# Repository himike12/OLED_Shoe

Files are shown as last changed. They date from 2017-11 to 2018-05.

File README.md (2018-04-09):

# OLED_Shoe

This is the git repository for both the mobile application as well as the hardware design and code.

The Hardware file includes all of the files relating to the hardware design as well as the software for the embedded microcontroller.

Dependencies:

Linux
For 64-bit Linux users, libc6:i386, libstdc++6:i386, libncurses5:i386 and libudev1:i386 need to be installed :
  * sudo dpkg --add-architecture i386
  * sudo apt-get update
  * sudo apt-get -y install libc6:i386 libstdc++6:i386 libncurses5:i386 libudev1:i386
  
From the Library Manager:
  * Adafruit_GFX_Library
  * BLEPeripheral
  * PL_microEPD

Programmer:
  * CMSIS-DAP

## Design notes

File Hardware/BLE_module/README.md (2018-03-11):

The BLE_Serial_Echo and BLE_Serial_No_Echo use the Arduino IDE.

In order to use the Arduino IDE with the Nordic nRF52, you need to install aditional stuff in the Arduino IDE. The link below has instructions on how to install everything needed.

https://github.com/sandeepmistry/arduino-nRF5

File Contents

BLE_Serial_Programs - Contains test programs related to bluetooth low energy (BLE)

Combine_Screen_and_BLE - Contains test programs that combine the use of BLE and the ePaper screens

Screen_Test_Code - Contains test code related to displaying content on the ePaper screens

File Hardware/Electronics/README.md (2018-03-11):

File Contents

Adafruit_Designs - Contains the original schematic diagrams and PCB designs for parts that were used in the project. Some of the schematic diagrams have been coped and modified to work in the project.

ePaperShoe - Contains the schematic diagrams and PCB designs created for the project

nRF52_Reference_Scematics - Contains the reference documents for the Nordic nRF52-DK

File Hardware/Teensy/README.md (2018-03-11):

File Contents

Teensy_Game_OF_Life - A program for the Teensy that will display the game of life on the ePaper screen

Teensy_Screen_Demo - A program for the Teensy that will display a test image on the ePaper screen

Working_PL_Teensy_GFXDemo - A program for the Teensy that will display a GFX demo on the ePaper screen

Working_PL_Teensy_HelloWorld - A program for the Teensy that will display text saying "Hello World" on the ePaper screen

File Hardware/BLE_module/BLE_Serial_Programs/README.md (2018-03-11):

File contents

BLE_Serial_Echo - A program for the Nordic nRF52 that will communicate with a mobile device running an application that will connect to the microcontroller using BLE UART, such as Bluefruit from Adafruit. The text entered on the mobile device will be echoed back the to the mobile device and sent to a serial connection  and vice versus.

BLE_Serial_Echo - A program for the Nordic nRF52 that will communicate with a mobile device running an application that will connect to the microcontroller using BLE UART, such as Bluefruit from Adafruit. The text entered on the mobile device will be sent to a serial connection and vice versus.

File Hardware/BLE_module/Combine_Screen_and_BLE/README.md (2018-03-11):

File Contents

recieve_data_and_display_modes - A program for the Nordic nRF52 that will display different images on the ePaper screen and run in different modes depending on the instructions that it receives over BLE UART.

recieve_data_and_display_the_text - A program for the Nordic nRF52 that will display text that it has received over BLE UART.

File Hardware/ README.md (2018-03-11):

File contents

BLE_module - Contains all of the code written for the Nordic nRF52832 microcontroller

Electronics - Contains all of the schematic diagrams and PCB designs created as well as reference designs from Adafruit and Nordic

Example Code - Contains reference documents from PlasticLogic, Paperino, and Img2Code

Teensy - Contains all of the code written for the Teensy microcontroller

TestImages - Contains all the images that have been converted to be displayed on the ePaper screens

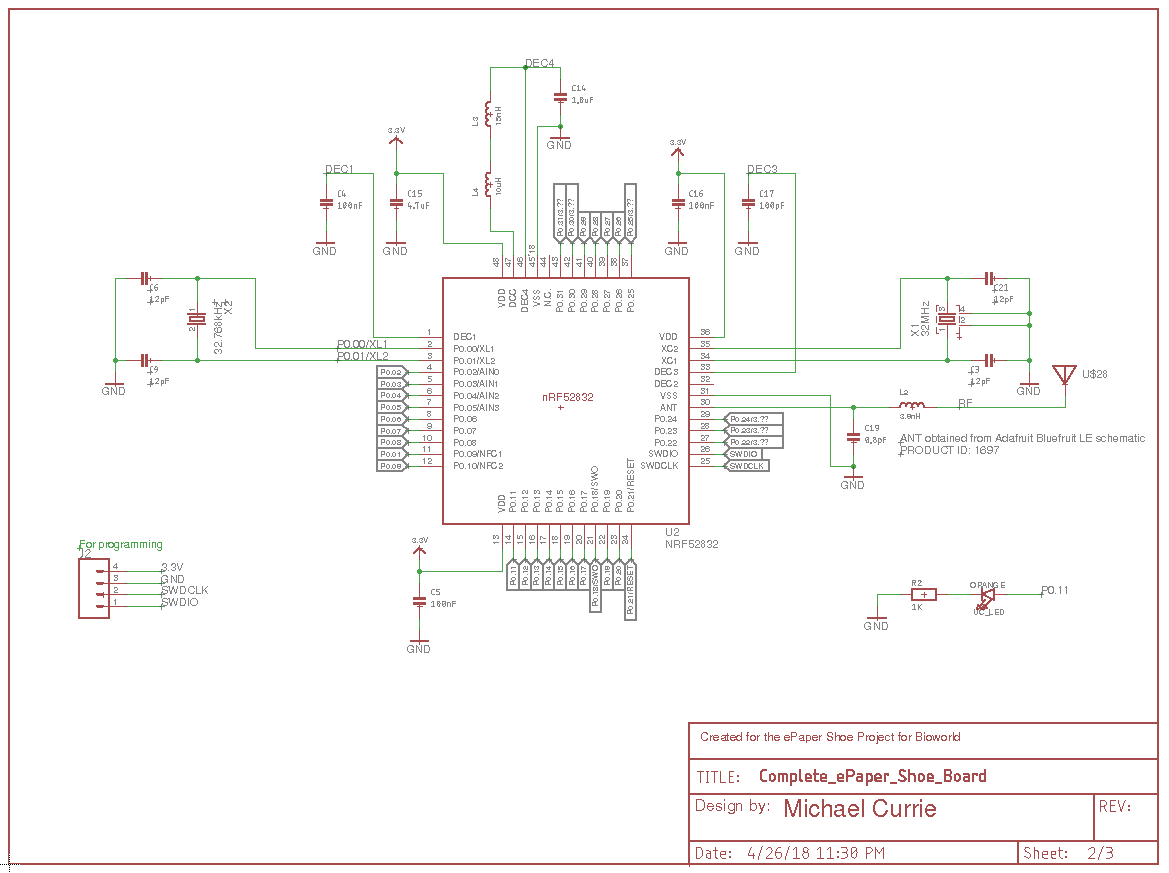
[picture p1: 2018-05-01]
Hardware/Images/Schematic2.png

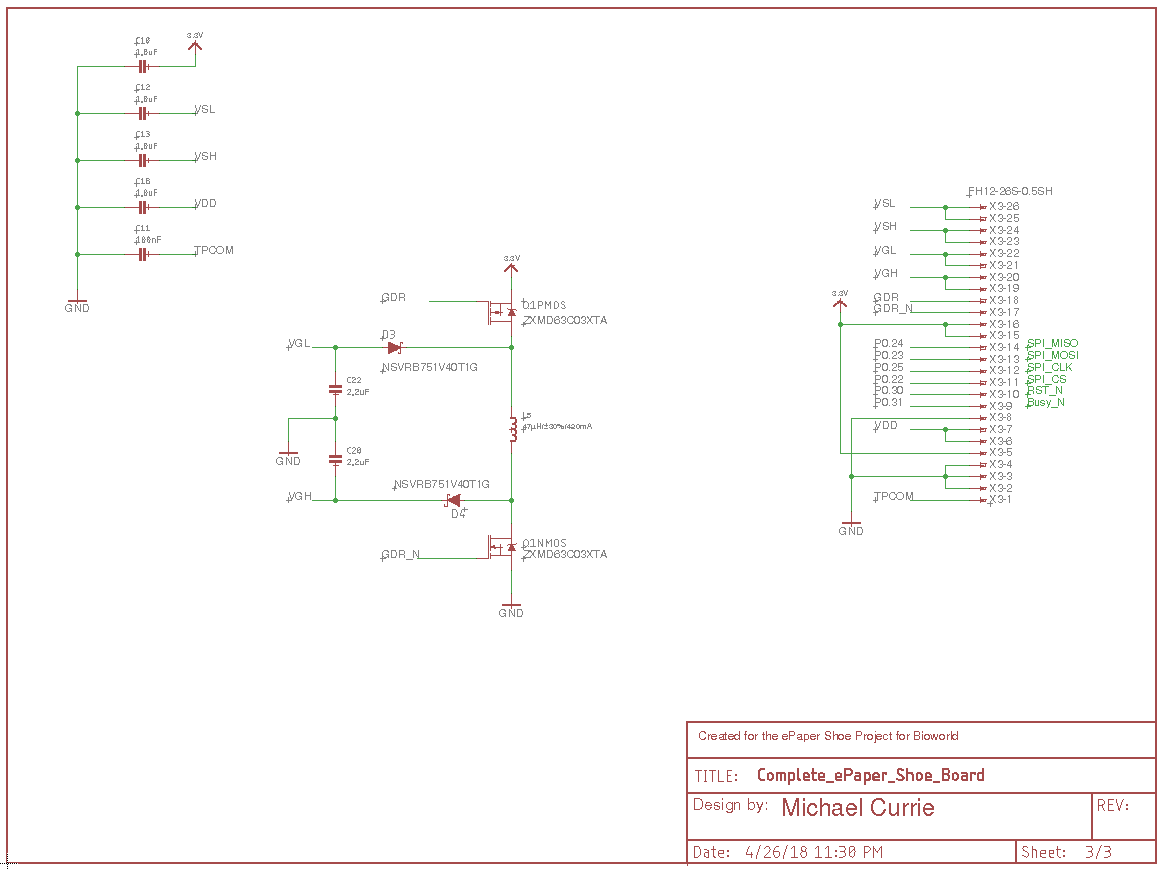
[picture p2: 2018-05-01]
Hardware/Images/Schematic3.png

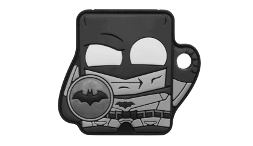
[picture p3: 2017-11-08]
Hardware/ExampleCode/PlasticLogic_SD_Card_Contents/S021_T1.1/img/batman9.PNG

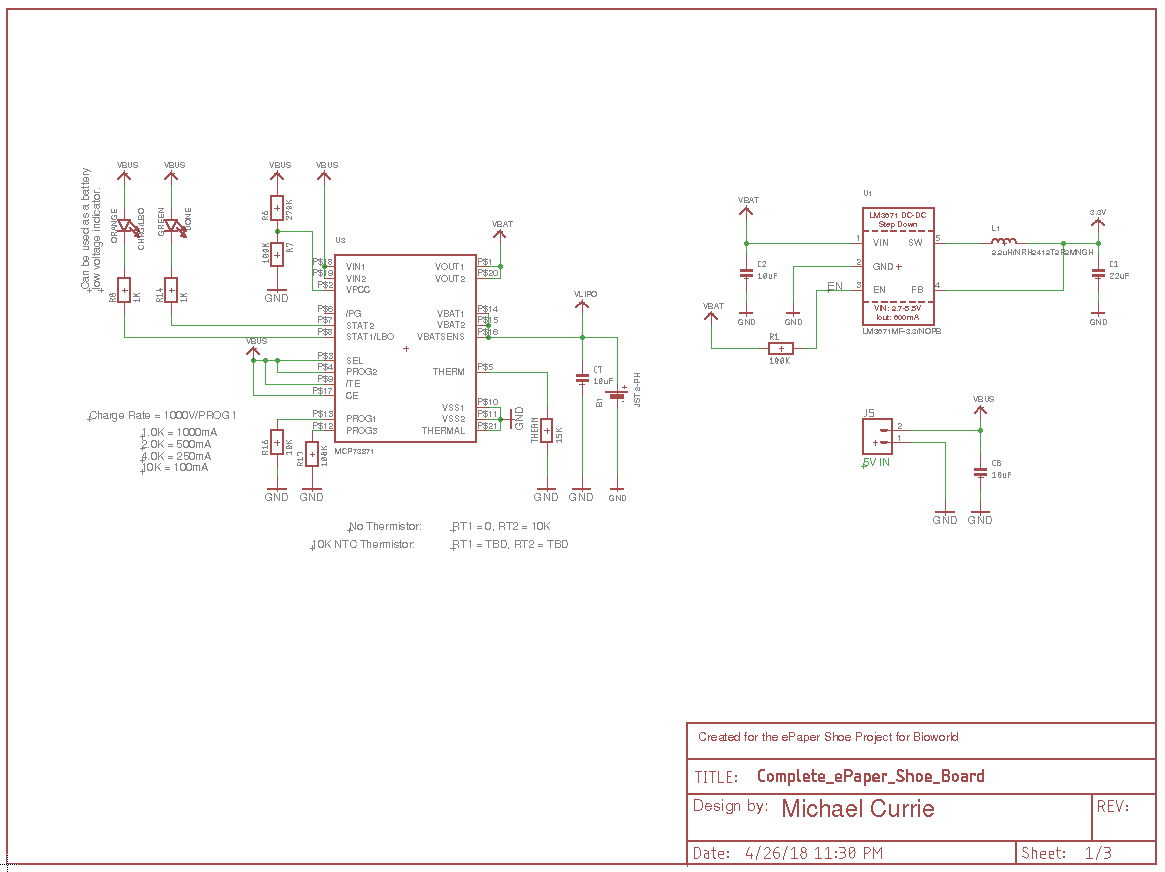
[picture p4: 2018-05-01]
Hardware/Images/Schematic1.png

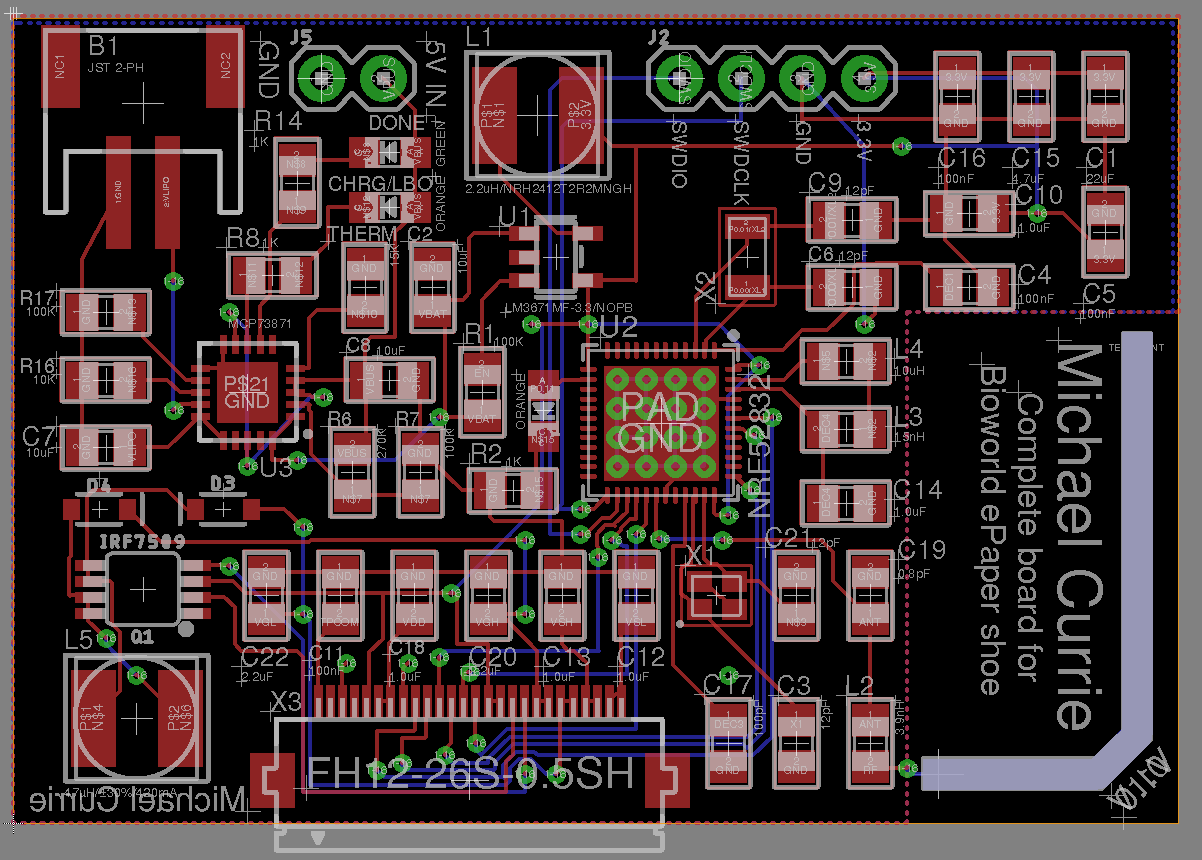
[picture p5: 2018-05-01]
Hardware/Images/PCB.png

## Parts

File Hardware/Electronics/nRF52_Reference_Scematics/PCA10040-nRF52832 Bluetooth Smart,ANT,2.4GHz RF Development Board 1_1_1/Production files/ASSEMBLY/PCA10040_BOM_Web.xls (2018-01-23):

Bill of material
PCB: | PCA10040
Version: | 1.1.1
Designator | Value | Description | Footprint Doc | Manufacturer | Manufacturer Part Number
Bat1 | Bat Holder CR2032 | Bat Holder CR2032 SMD | CR2032_HOLDER_SMD | Comfortable | BC-2001
C1, C2, C11, C12 | 12pF | Capacitor, NP0, ±2% | 0402
C3 | 0.8pF | Capacitor, NP0, ±5% | 0402
C4, C5, C8, C18, C19, C21, C24, C25, C26, C27, C28, C29, C32, C34, C35, C36, C38, C39, C40, C41, C44, C45, C46, C47 | 100nF | Capacitor, X7R, ±10% | 0402
C6, C13 | N.C. | Not mounted | 0402
C7 | 100pF | Capacitor, NP0, ±5% | 0402
C9 | 4.7µF | Capacitor, X5R, ±10% | 0603
C10, C16, C17 | 1.0µF | Capacitor, X7R, ±10% | 0603
C15 | 1.2pF | Capacitor, NP0, ±0.1pF | 0402
C20, C31, C33 | 10µF | Capacitor, X5R, ±20% | 0603
C22, C23 | 18pF | Capacitor, NP0, ±5% | 0402
C30 | 10nF | Capacitor, X7R, ±10% | 0402
C37 | 10pF | Capacitor, NP0, ±2% | 0402
C42, C43 | 300pF | Capacitor, NP0, ±5% | 0402
C48, C49, C50, C51 | 1.0µF | Capacitor, X5R, ±5% | 0402
D1 | SD103ATW-7-F | Surface Mount Schottky Barrier Diode Array | SOT-363 | Diodes Incorporated | SD103ATW-7-F
D2 | PRTR5V0U2X | Ultra low capacitance double rail-to-rail ESD protection diode | SOT-143B | NXP | PRTR5V0U2X
D3, D4, D5, D6 | 1PS79SB30.115 | Diode Schottky Vf=0.38, Vr=40V, If=200mA, Ir=500nA | SOD-523 | NXP | 1PS79SB30.115
J1 | MM8130-2600 | Coaxial Connector with Switch | COAXIAL-SWF | Murata | MM8130-2600
J2 | MicroUSB-B | MicroUSB-B-SMT | USB-Micro-B-RA-SMD-PiP | Allen Creations Corp. | AJU55-BS2111-L
L1 | 3.9nH | Inductor, 170mA, ±0.1nH | 0402 | Murata | LQP15MN3N9B02D
L2 | 10µH | Inductor, 80mA, ±10% | 0603 | Taiyo Yuden | LBMF1608T100K
L3 | 15nH | Inductor, 320mA, ±5% | 0402 | Taiyo Yuden | HK100515NJ-T
LD5 | LTST-C195KGJRKT | Ultra bright AlInGaP Bi-Color LED | LED_DUAL_0606 | Lite-On Inc | LTST-C195KGJRKT
LED1, LED2, LED3, LED4 | L0603G | LED SmartLED Green 570nm 0603 | 0603 | OSRAM Opto Semi | LG L29K-G2J1-24-Z
P1, P3 | Socket 1x8 | Socket 1x8, 2.54mm (100mil), SMD | SOCKET_1x8_SMD | WCON | 2171-108MS0CUNR1
P2 | Socket 1x6 | Socket 1x6, 2.54mm (100mil), SMD | SOCKET_1x6_SMD | WCON | 2171-106MS0CUNR1
P4 | Socket 1x10 | Socket 1x10, 2.54mm (100mil), SMD | SOCKET_1x10_SMD | WCON | 2171-110MS0CUNR1
P5 | Pin Hdr 2x3 | Pin Header 2x3, 2.54mm (100mil) SMD | HDR_2x3-SMD | WCON | 1125-1203S0M116R1
P6 | Socket 1x9 | Socket 1x9, 2.54mm (100mil), SMD | SOCKET_1x9_SMD | WCON | 2171-109MS0CUNR1
P7, P9 | Pin List 1x8 | Pin List 1x8, 2.54mm (100mil), SMD | LIST_1x8_SMD
P8 | Pin List 1x6 | Pin List 1x6, 2.54mm (100mil), SMD | LIST_1x6_SMD
P10 | Pin List 1x10 | Pin List 1x10, 2.54mm (100mil), SMD | LIST_1x10_SMD
P11 | Socket 2x3 | Socket 2x3, 2.54mm (100mil), SMD | SOCKET_2x3_SMD-2.54mm-bottom
P12 | Pin List 1x9 | Pin List 1x9, 2.54mm (100mil), SMD | LIST_1x9_SMD
P13, P15 | Pin Header 2x8 | Pin Header 2x8, 2.54mm (100mil) | HDR_2x8
P14 | Pin Header 2x6 | Pin Header 2x6, 2.54mm (100mil) | HDR_2x6
P16 | Pin Header 2x10 | Pin Header 2x10, 2.54mm (100mil) | HDR_2x10
P17 | Pin Header 2x9 | Pin Header 2x9, 2.54mm (100mil) | HDR_2x9
P18, P19 | Pin Header 2x5, 1.27mm | Pin Header 2x5, 1.27mm (50mil), SMD, Keying Shroud | HDR_2x5-SMD-1.27mm | WCON | 3132-10MS0BK00R1
P20 | Pin List 1x8 | Pin List 1x8, 2.54mm (100mil), SMD | LIST_1x8_SMD | WCON | 1125-1108S0M116R2
P21, P22 | Pin List 1x2, Angled | Pin List 1x2, 2.54mm (100mil), Right Angled, SMD | LIST_ANG_1x2-SMD-2.54MM | WCON | 1125B-1102S0Z135R2
P23 | FPC 0.5mm RA SMD | 0.5mm FPC, 5P,Right Angle SMT,Double Contact,H=1.2mm,White, Goldflash | FPC_05P-0.5mm-RA-SMD | WCON | 5141-05RZDNWR02
Q1, Q2 | FDG6321C | Fairchild, FDG6321C, Dual N & P Channel Digital FET | SC70-6 | Fairchild | FDG6321C
R1, R2, R3, R4, R19, R20 | 220R | Resistor, ±1%, 0.063W | 0402
R5, R8, R9, R10, R11, R12 | 10k | Resistor, ±1%, 0.063W | 0402
R6, R27, R28, R37 | N.C. | Not mounted | 0402
R7 | 47k | Resistor, ±1%, 0.063W | 0402
R13, R14 | 39R | Resistor, ±1%, 0.063W | 0402
R15, R16 | 150R | Resistor, ±1%, 0.063W | 0402
R17 | 6k8 | Resistor, ±1%, 0.063W | 0402
R18 | 1k | Resistor, ±1%, 0.063W | 0402
R21, R22, R23, R24, R29, R30 | 4k7 | Resistor, ±1%, 0.063W | 0402
R25, R26, R38 | 0R | Resistor, ±5%, 0.063W | 0402
R31, R32 | 12k | Resistor, ±1%, 0.063W | 0402
R33, R34, R35, R36 | 100k | Resistor, ±1%, 0.063W | 0402
R39 | 1M0 | Resistor, ±1%, 0.063W | 0402
R40, R41, R42, R43 | 18k | Resistor, ±1%, 0.063W | 0402
SW1, SW2, SW3, SW4, SW5 | PB SW | Tactile Switch, SPNO, SMD, 6.5x6.2x2.5mm | ALPS_SKHUxxx010_WO_GND | Dalywell | TS604VM1-025BR-R
SW6 | Switch | SMD slide Switch (ON-ON) | JS202011SCQN | Dalywell | SS206VM-G2-LLR-R
U1 | nRF52832-QFAA | Multi-protocol Bluetooth Low Energy and 2.4GHz proprietary system-on-chip | QFN-48 | Nordic Semiconductor | nRF52832-QFAA
U2 | ATSAM3U2CA-AU | IC MCU 32bit 128kB flash 100LQFP | LQFP-100 | Atmel | ATSAM3U2CA-AU
U3 | AP7333-33SAG-7 | 300mA, Low Quiescent Current, Fast Transient Low Dropout Linear Regulator | SOT-23-3 | Diodes Incorporated | AP7333-33SAG-7
U4, U5, U6 | NX3DV2567 | Low-ohmic four-pole double-throw analog switch | XQFN-16 | NXP Semiconductors | NX3DV2567GU
U7 | PCAL6408A | 8-bit I2C-bus I/O expander with interrupt output | XQFN-16 | NXP Semiconductors | PCAL6408AHK
X1 | 32MHz | XTAL SMD 2016, 32MHz, Cl=8pF, Tol: ±10ppm, Stab: ±10ppm | XTAL_2016 | Epson Toyocom | Q22FA12800025
X2 | 32.768kHz | EPSON TOYOCOM - FC-135 32.768KHZ ±20PPM,9.0PF - CRYSTAL, SM, WATCH | XTAL_3215 | Epson Toyocom | FC-135 32.768KHZ ±20PPM,9.0PF
X3 | 12MHz | XTAL SMD 3225, 12MHz, 18pF, ±30ppm | BT-XTAL_3225 | TXC Corporation | 7M-12.000MAAJ-T

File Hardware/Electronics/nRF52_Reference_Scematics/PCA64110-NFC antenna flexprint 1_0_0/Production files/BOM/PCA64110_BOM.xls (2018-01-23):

Bill of material
PCB: | PCA64110
Version: | 1.0.0
Supplier | Supplier Part Number | Contact information
Elprint Norge | 203406 | Web: www.elprint.no Phone: +47 55 92 55 00

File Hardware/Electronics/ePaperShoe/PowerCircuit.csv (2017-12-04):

Added | Qty | Value | Device | Package | Parts | Description | DESIGNER | PROD_ID | VERSION
y | 1 |  | CONN_04 | 1X04 | J1 | Multi connection point. Often used as Generic Header-pin footprint for 0.1 inch spaced/style header connections |  | CONN-09696
y | 3 | 100K | RESISTOR0805_NOOUTLINE | 0805-NO | R1, R7, R17 | Resistors
y | 1 | 10K | RESISTOR0805_NOOUTLINE | 0805-NO | R16 | Resistors
y | 3 | 10uF | CAP_CERAMIC0805-NOOUTLINE | 0805-NO | C2, C7, C8 | Ceramic Capacitors
y | 1 | 15K | RESISTOR0805_NOOUTLINE | 0805-NO | THERM | Resistors
y | 2 | 1K | RESISTOR0805_NOOUTLINE | 0805-NO | R8, R14 | Resistors
y | 1 | 2.2uH/NRH2412T2R2MNGH | INDUCTORNRH2412T | INDUCTOR_TAIYOYUDEN_NRH2412T | L1 | Inductors
y | 1 | 22uF | CAP_CERAMIC0805-NOOUTLINE | 0805-NO | C1 | Ceramic Capacitors
y | 1 | 270K | RESISTOR0805_NOOUTLINE | 0805-NO | R6 | Resistors
n/a | 1 | FRAME-LETTER-MICHAELNO_PACKAGE | FRAME-LETTER-MICHAELNO_PACKAGE | DUMMY | FRAME1 | Schematic Frame - Letter | Nobody |  | v01
y | 1 | GREEN | LED0805_NOOUTLINE | CHIPLED_0805_NOOUTLINE | DONE | LED
y | 1 | JST 2-PH | BATTERY | JSTPH2 | B1 | CR1220 SMT - Digikey: 3001K-ND
y | 1 | LM3671MF-3.3/NOPB | VREG_LM3671 | SOT23-5 | U1 | LM3671 - 600mA DC-DC Step-Down Converter
y | 1 | MCP73871 | MCP73871 | QFN20_4MM | U3 | MCP73871 Lithium Polymer Battery Charger
y | 1 | MicroUSB | USBMICRO_20329 | 4UCONN_20329 | CN4 | USB Connectors
y | 1 | ORANGE | LED0805_NOOUTLINE | CHIPLED_0805_NOOUTLINE | CHRG/LBO | LED

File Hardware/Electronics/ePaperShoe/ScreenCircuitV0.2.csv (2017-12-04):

Added top order | Part | Value | Device | Package | Description | DESIGNER | MF | MPN | OC_FARNELL | OC_NEWARK | PACKAGE | PROD_ID | SUPPLIER | VALUE | VERSION
y | C1 | 1.0uF | 1.0UF-1206-50V-10% | 1206 | 1µF ceramic capacitors |  |  |  |  |  |  | CAP-09822 |  | 1.0uF
y | C2 | 1.0uF | 1.0UF-1206-50V-10% | 1206 | 1µF ceramic capacitors |  |  |  |  |  |  | CAP-09822 |  | 1.0uF
y | C3 | 1.0uF | 1.0UF-1206-50V-10% | 1206 | 1µF ceramic capacitors |  |  |  |  |  |  | CAP-09822 |  | 1.0uF
y | C4 | 1.0uF | 1.0UF-1206-50V-10% | 1206 | 1µF ceramic capacitors |  |  |  |  |  |  | CAP-09822 |  | 1.0uF
y | C5 | 0.1uF | 0.1UF-0603-100V-10% | 603 | 0.1µF ceramic capacitors |  |  |  |  |  |  | CAP-08390 |  | 0.1uF
y | C6 | 4.7uF | 4.7UF-1206-16V-(+80/-20%) | 1206 | 4.7µF ceramic capacitors |  |  |  |  |  |  | CAP-10300 |  | 4.7uF
y | C7 | 4.7uF | 4.7UF-1206-16V-(+80/-20%) | 1206 | 4.7µF ceramic capacitors |  |  |  |  |  |  | CAP-10300 |  | 4.7uF
y | D3 | 0.5A/40V/420mV | DIODE-SCHOTTKY-PMEG4005EJ | SOD-323 | Schottky diode |  |  |  |  |  |  | DIO-10955 |  | 0.5A/40V/420mV
y | D4 | 0.5A/40V/420mV | DIODE-SCHOTTKY-PMEG4005EJ | SOD-323 | Schottky diode |  |  |  |  |  |  | DIO-10955 |  | 0.5A/40V/420mV
n/a | FRAME1 | FRAME-LETTER-MICHAELNO_PACKAGE | FRAME-LETTER-MICHAELNO_PACKAGE | DUMMY | Schematic Frame - Letter | Nobody |  |  |  |  |  |  |  |  | v01
y | J1 |  | CONN_08";"1X08 | Multi connection point. Often used as Generic Header-pin footprint for 0.1 inch spaced/style header connections |  |  |  |  |  |  | CONN-08438
y | L1 | 47µH/±30%/750mA | INDUCTOR-CR54-47UH | CR54 | Inductors |  |  |  |  |  |  | NDUC-10789 |  | 47µH/±30%/750mA
y | Q1 | IRF7509 | IRF7509 | MSOP8 | Dual N and P Channel MOSFET |  |  |  |  |  |  | TRANS-07913
y | U1 | XF2J-2624-11A | XF2J-2624-11A | OMRON_XF2J-2624-11A | FFC/FPC CONNECTOR, RECEPTACLE 26POS 1ROW |  |  | XF2J-2624-11A | - | 05M1981 | FFC/FPC CONNECTOR, RECEPTACLE 26POS 1ROW |  | OMRON ELECTRONIC COMPONENTS
y | X1 | FH12-26S-0.5SH | FH12-26S-0.5SH | FH12-26S-0.5SH | 0.5mm Pitch Connectors For FPC/FFC |  |  | FH12-26S-0.5SH(55) | 1324553 | 34M6172

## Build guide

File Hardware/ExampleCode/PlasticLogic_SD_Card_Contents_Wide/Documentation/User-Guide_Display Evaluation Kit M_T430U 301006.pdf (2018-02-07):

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
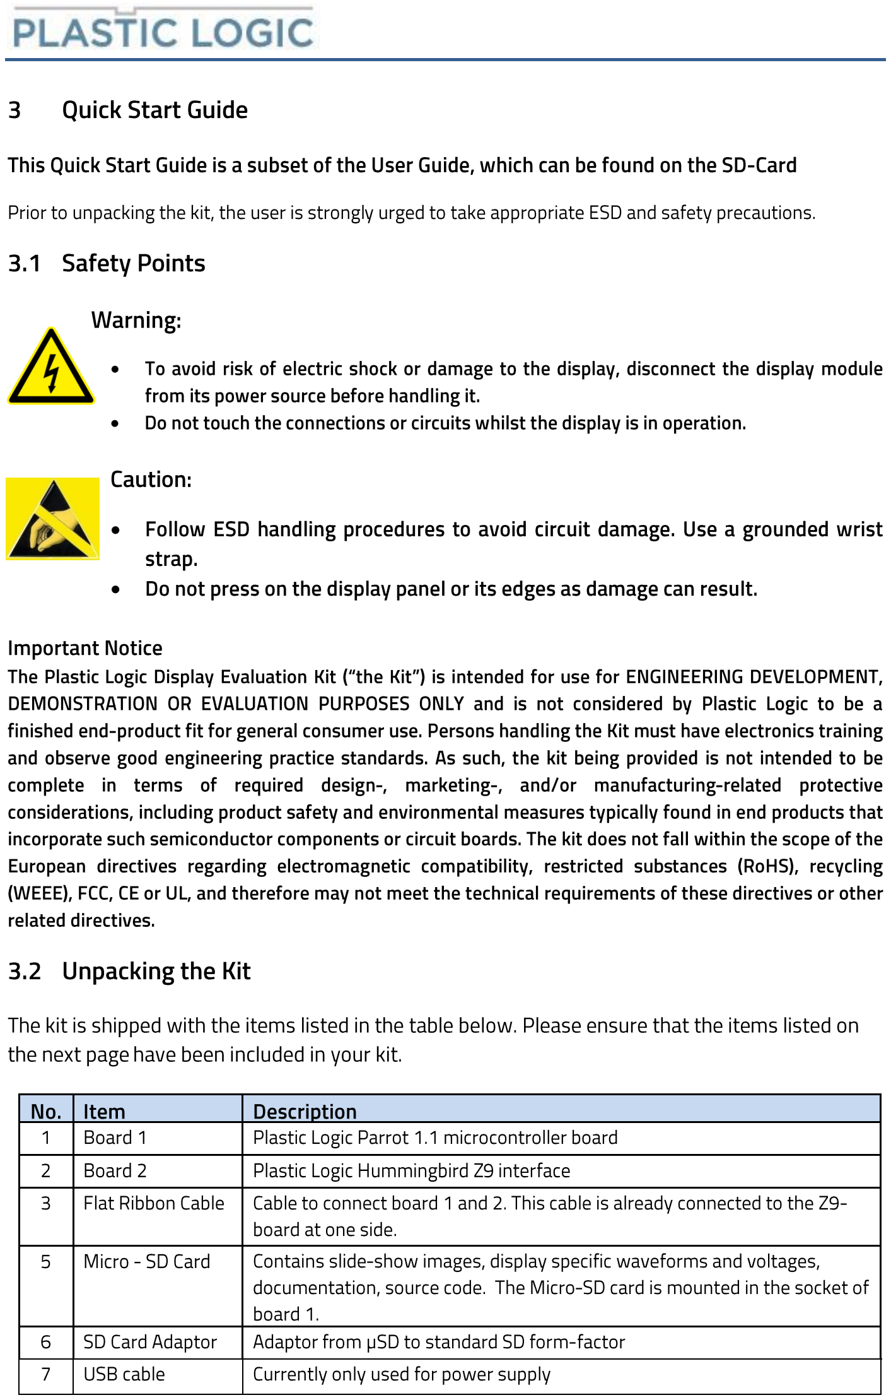
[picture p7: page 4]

••••

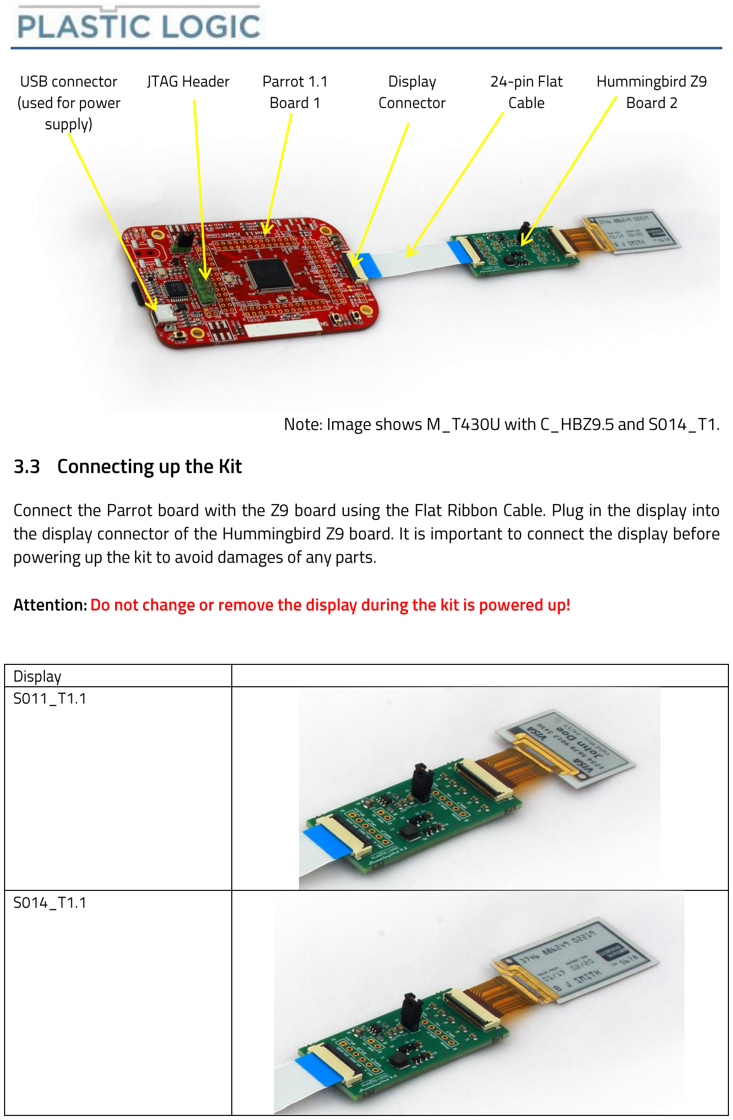
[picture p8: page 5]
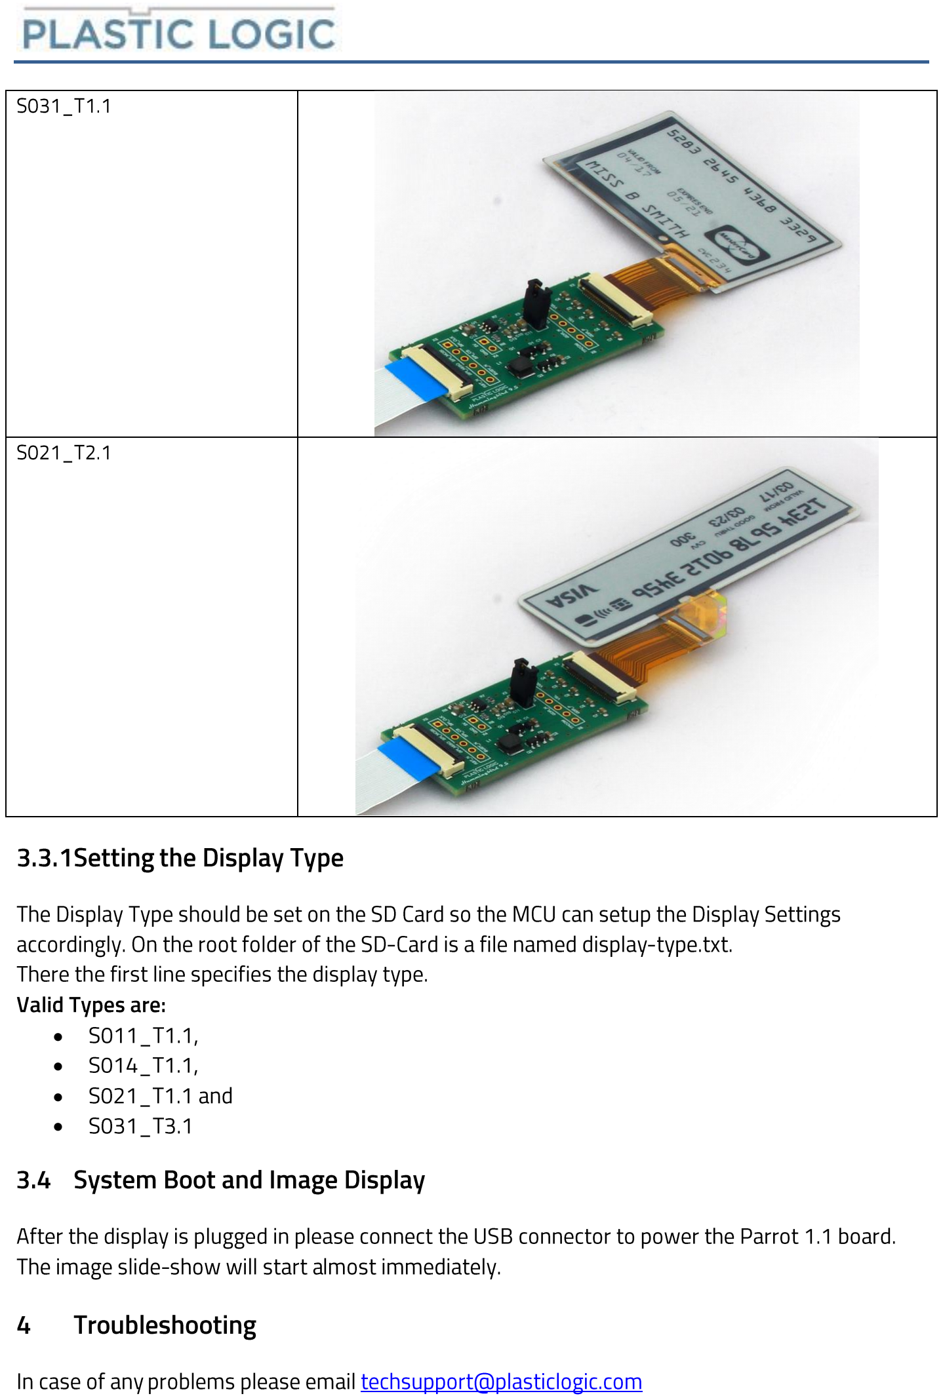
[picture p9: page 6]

••••

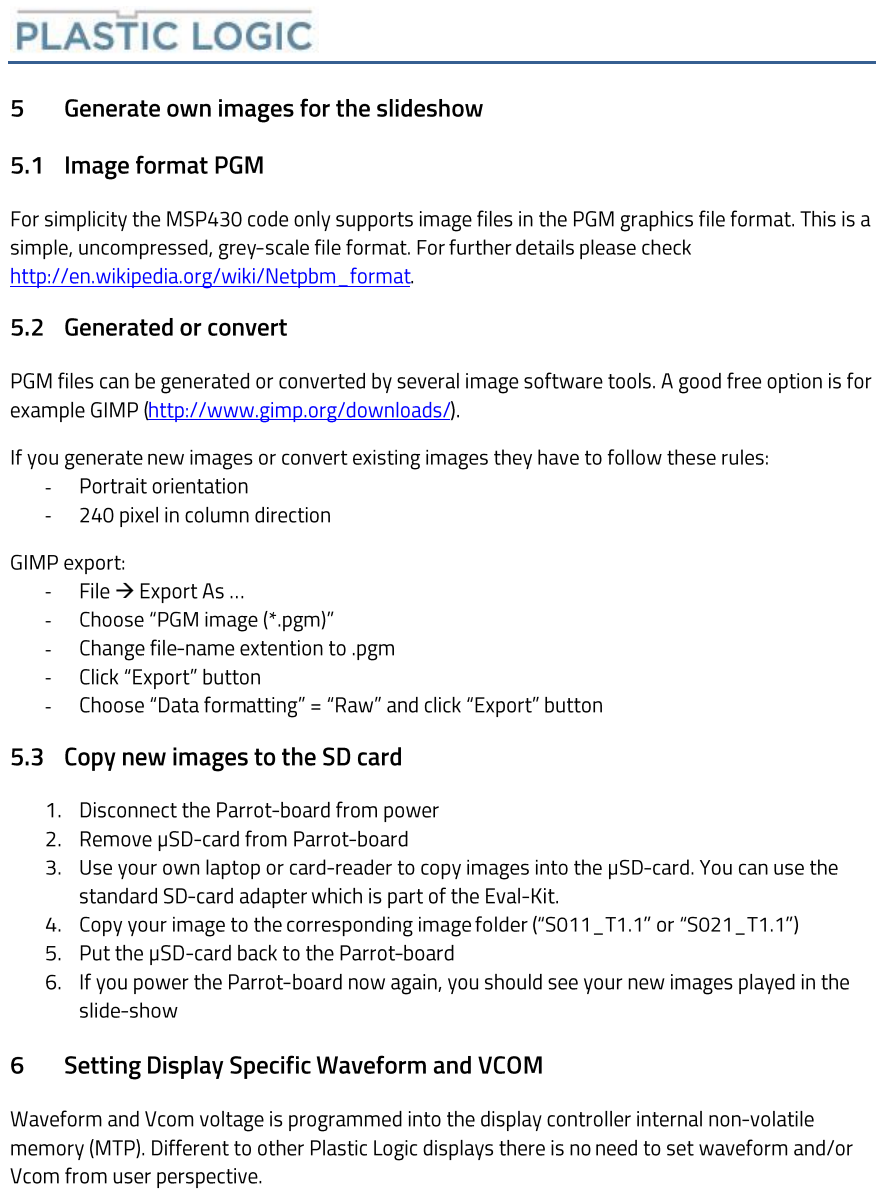
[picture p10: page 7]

- →

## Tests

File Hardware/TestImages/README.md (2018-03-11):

All of the images except for the Bioworld Logo are copyright Michael Currie 2018

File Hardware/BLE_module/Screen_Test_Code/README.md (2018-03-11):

File Contents

PL_Display_Image_Using_AdaGFX - A program for the Nordic nRF52 that will display a test image on the ePaper screen

PL_Display_Image_Using_AdaGFX_V2 - A second program for the Nordic nRF52 that will display a test image on the ePaper screen

PL_GFXDemo_NewLibVersion - A program for the Nordic nRF52 that will display a GFX demo on the ePaper screen

PL_GFXDemo_NewCustomLibVersion - The same as PL_GFXDemo_NewLibVersion except that the screen library is included in the file

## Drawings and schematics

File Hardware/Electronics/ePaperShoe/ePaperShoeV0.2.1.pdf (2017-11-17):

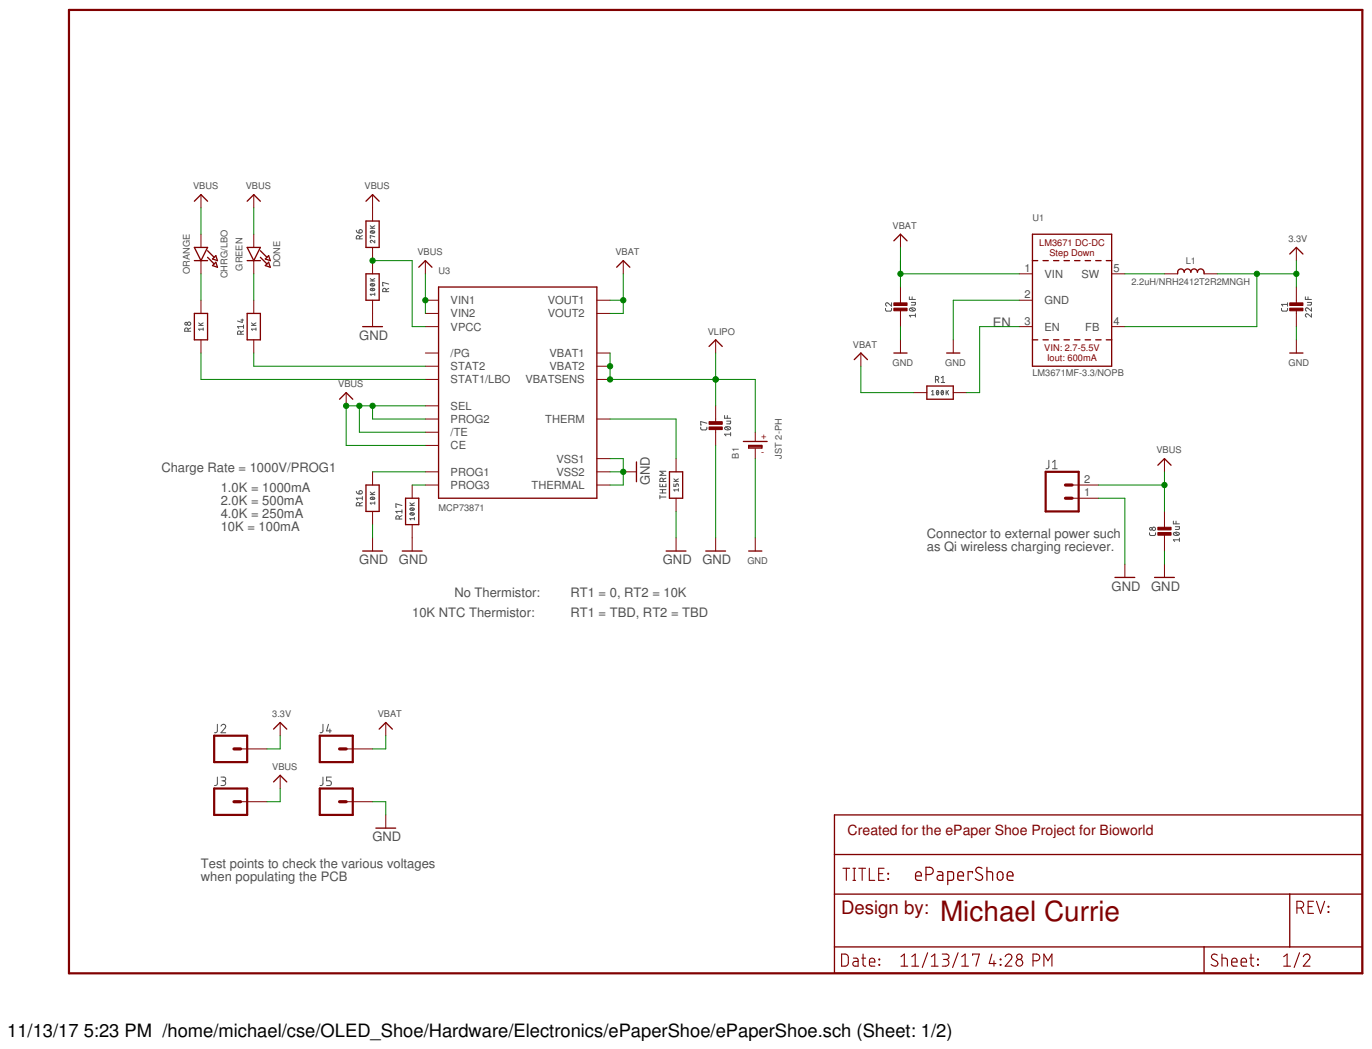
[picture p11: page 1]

as Qi wireless charging reciever. Connector to external power such

Created for the ePaper Shoe Project for Bioworld

Test points to check the various voltages when populating the PCB

Design by: Michael Currie

11/13/17 5:23 PM /home/michael/cse/OLED_Shoe/Hardware/Electronics/ePaperShoe/ePaperShoe.sch (Sheet: 1/2)

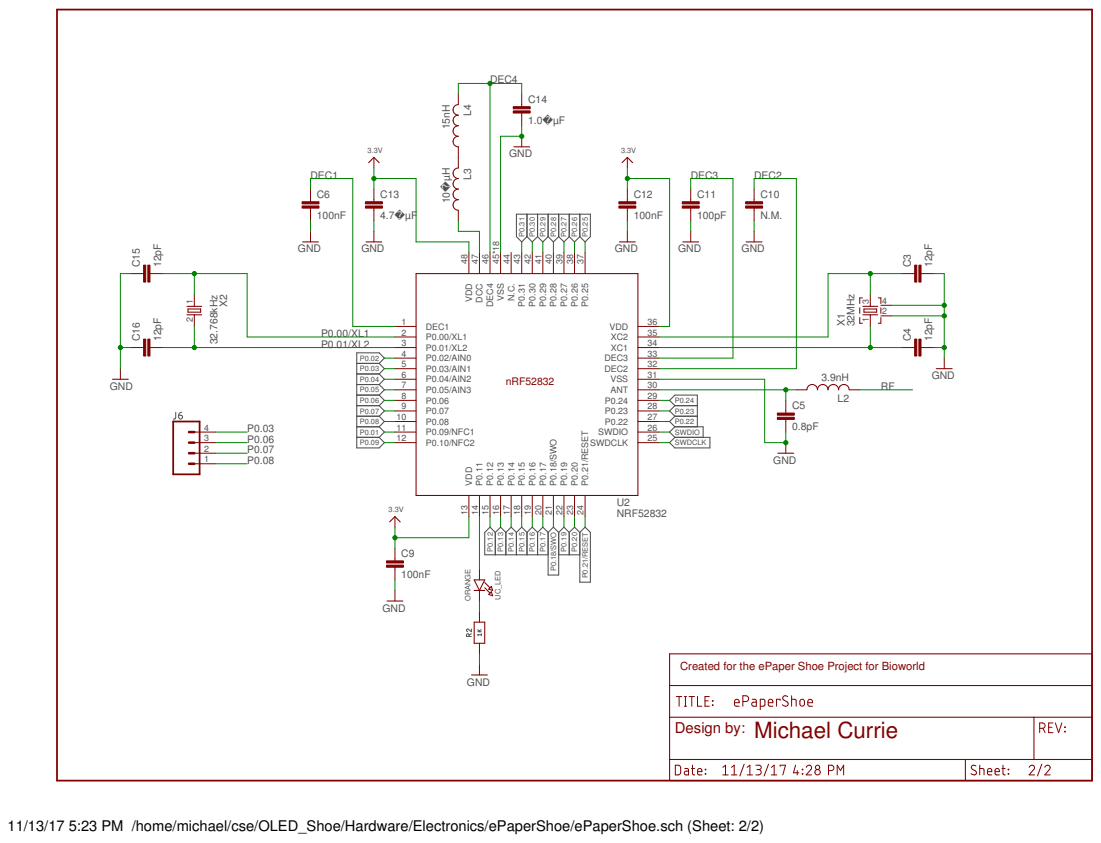
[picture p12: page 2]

Created for the ePaper Shoe Project for Bioworld

Design by: Michael Currie

11/13/17 5:23 PM /home/michael/cse/OLED_Shoe/Hardware/Electronics/ePaperShoe/ePaperShoe.sch (Sheet: 2/2)

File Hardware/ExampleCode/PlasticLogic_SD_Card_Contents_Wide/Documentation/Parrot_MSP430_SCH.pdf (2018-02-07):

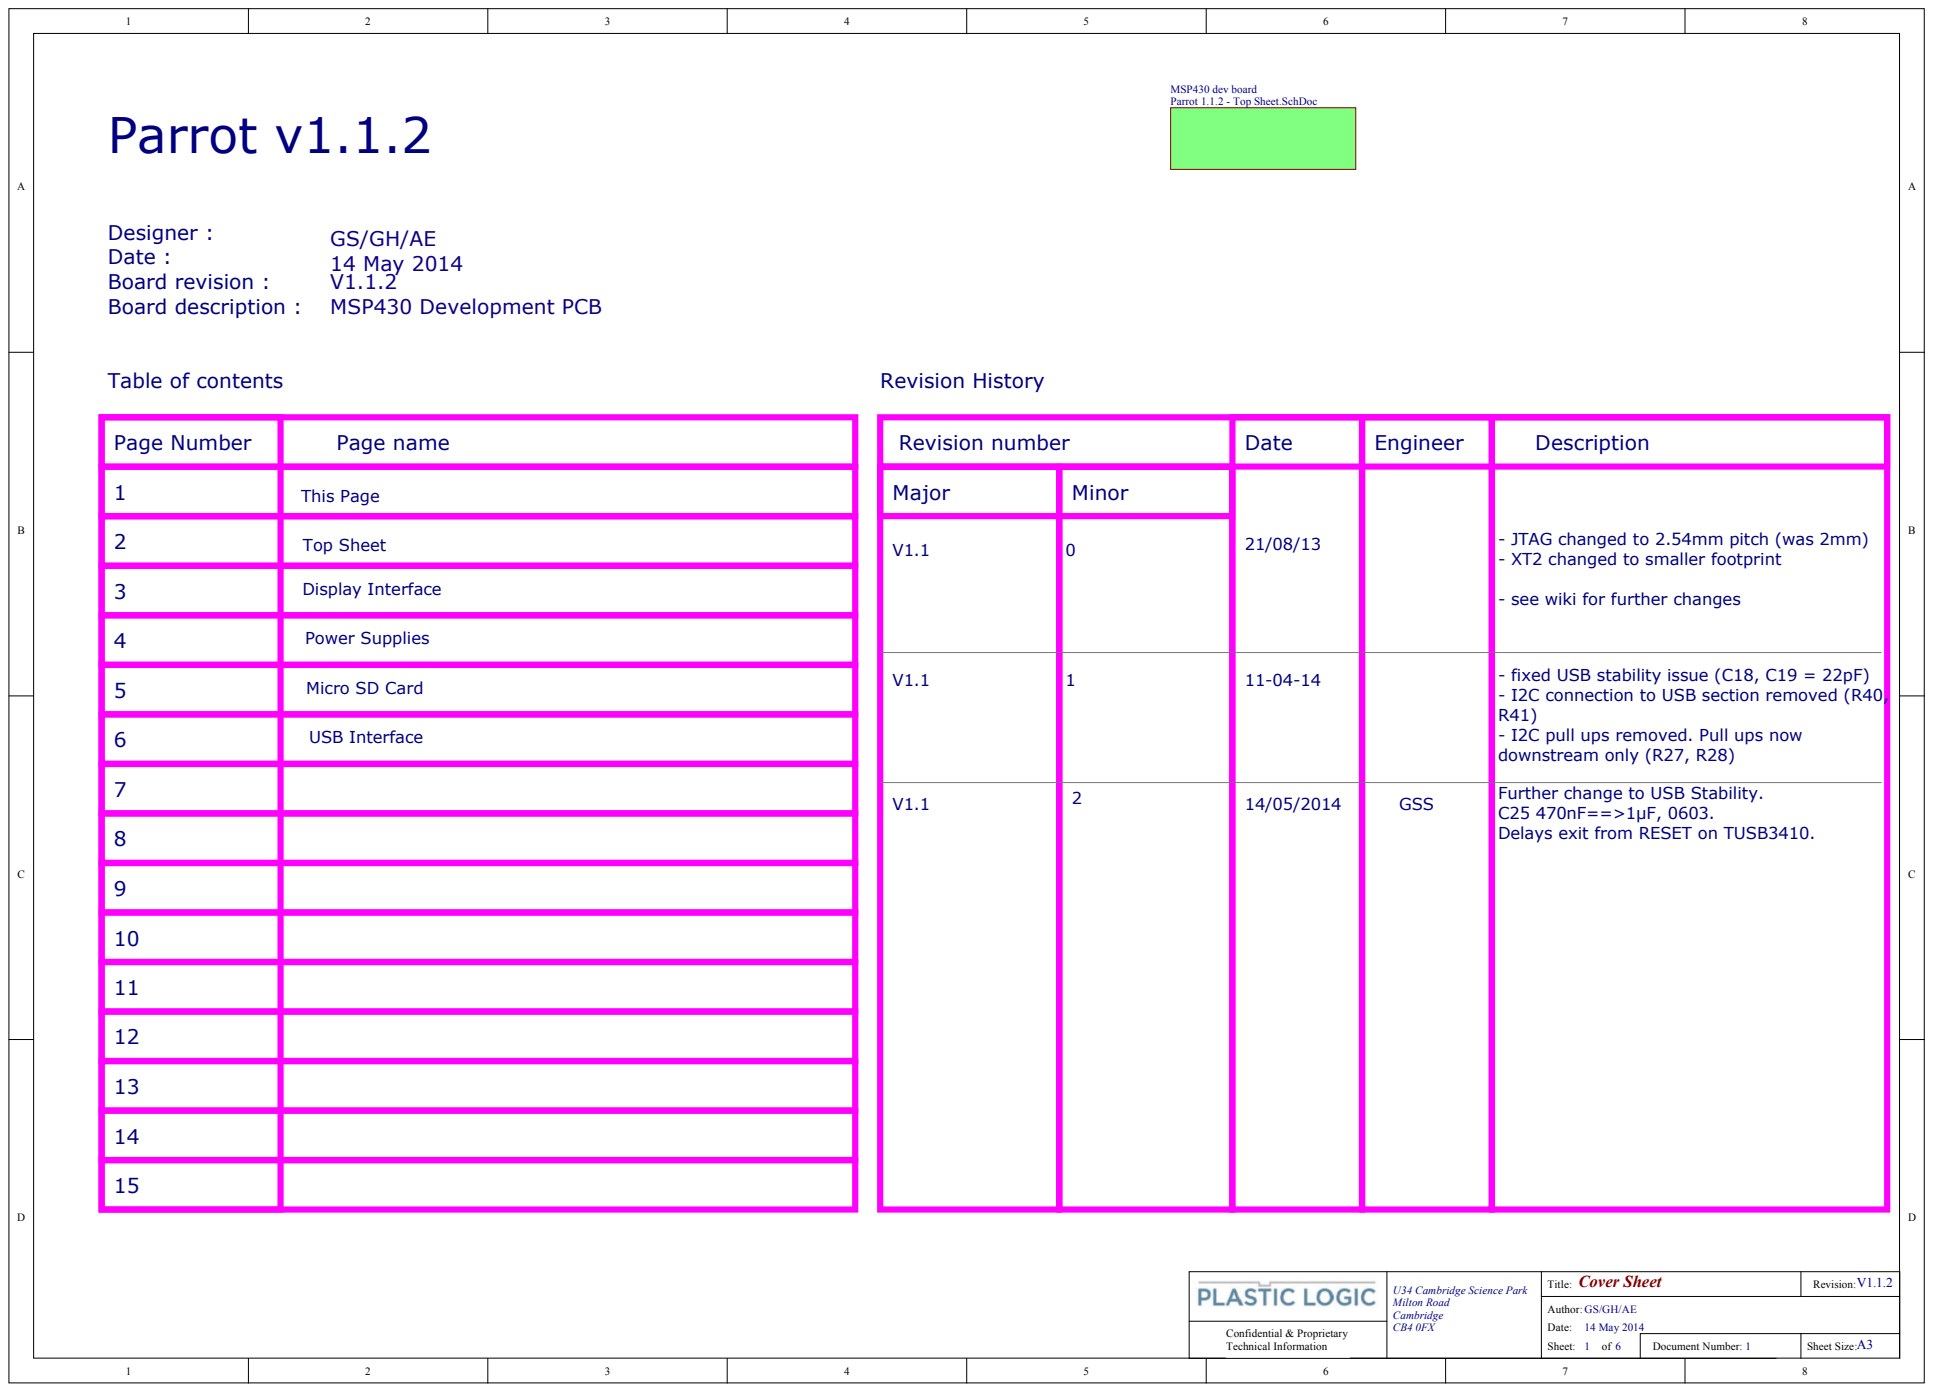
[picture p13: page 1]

MSP430 dev board
Parrot 1.1.2 - Top Sheet.SchDoc

- JTAG changed to 2.54mm pitch (was 2mm)
- XT2 changed to smaller footprint

3 | Display Interface

- see wiki for further changes

4 | Power Supplies

- fixed USB stability issue (C18, C19 = 22pF)
- I2C connection to USB section removed (R40,
- I2C pull ups removed. Pull ups now
downstream only (R27, R28)

5 | Micro SD Card

6 | USB Interface

Delays exit from RESET on TUSB3410.

Author: GS/GH/AE
Date:

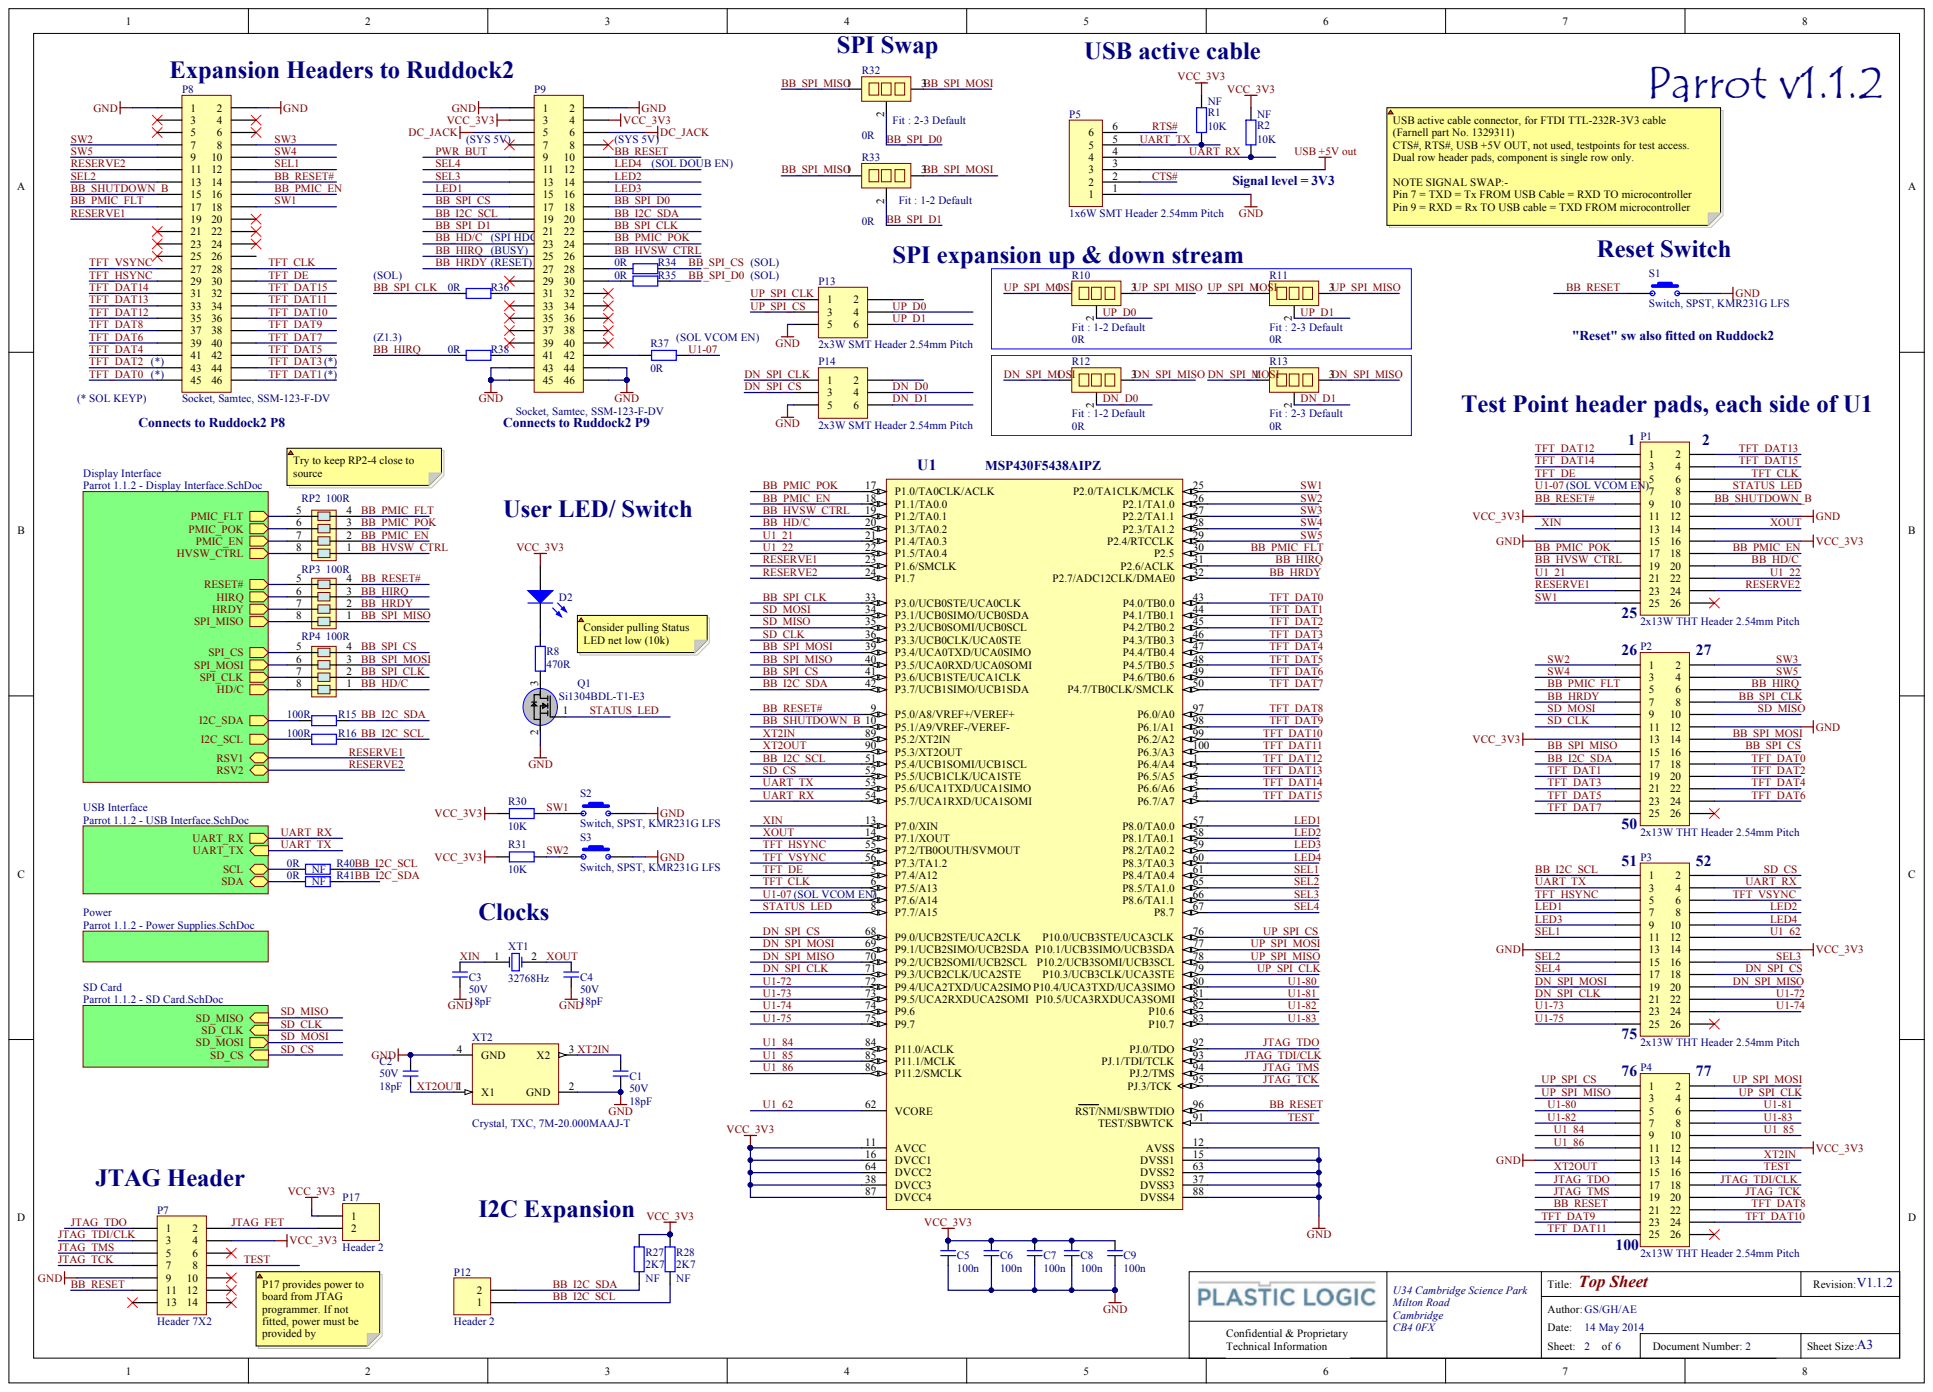
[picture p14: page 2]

USB act
(Farnel
CTS#, RTS#,
Dual row header pads, component

ive cable connector, for FTDI TTL-232R-3V3 cabl
l part

testpoints for
is single row only.

D BB_RESET "Reset" sw also fitted on Ruddock

Test Point header pads, each side of U1

User LED/ Switch GND SW1

SD Card
Parrot 1.1.2 - SD Card.SchDoc

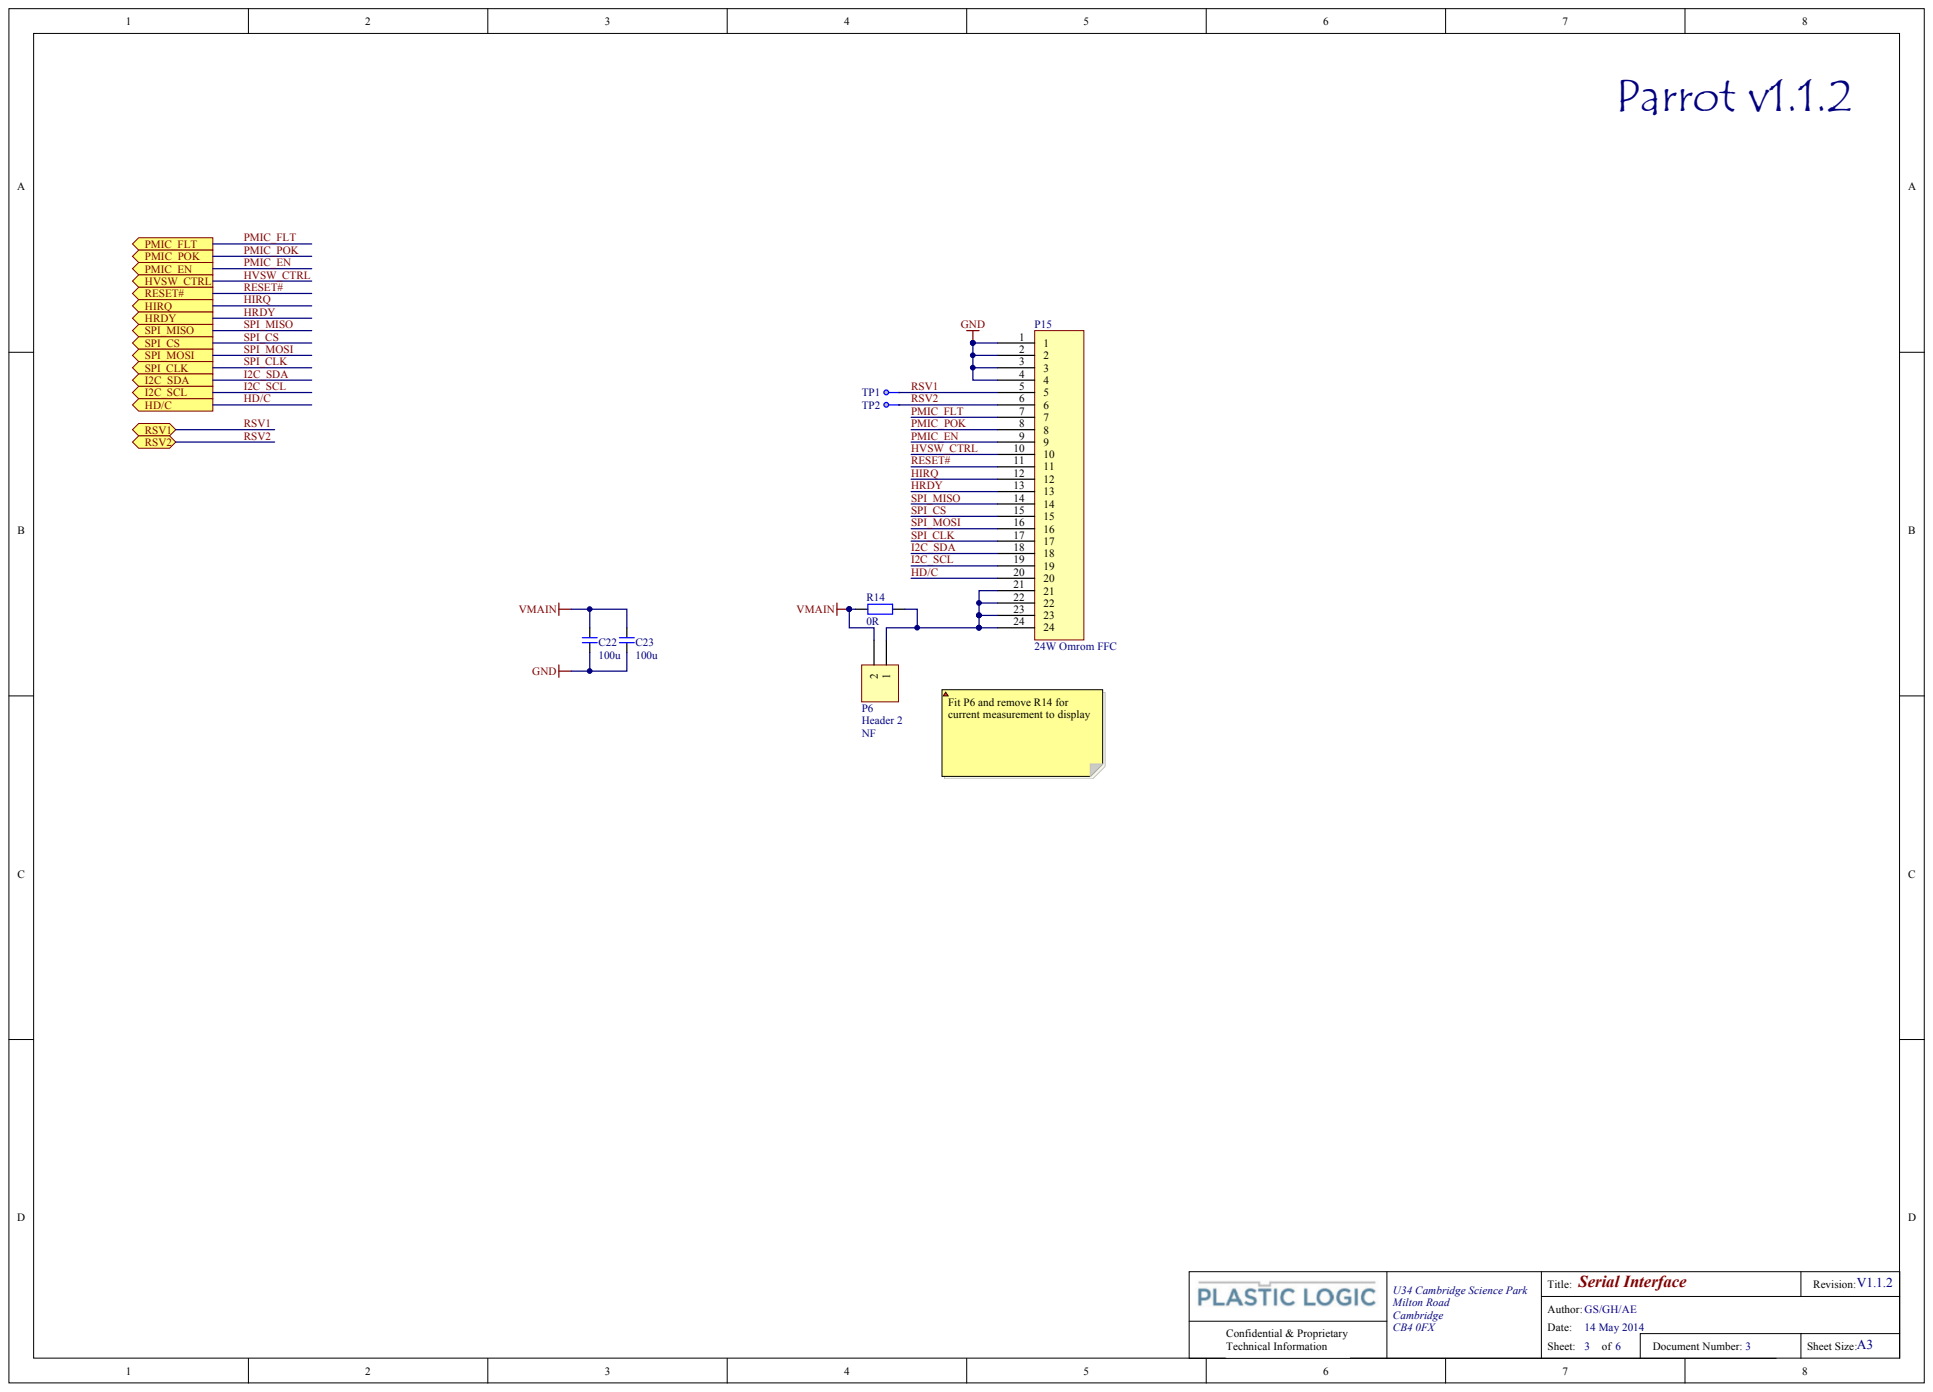
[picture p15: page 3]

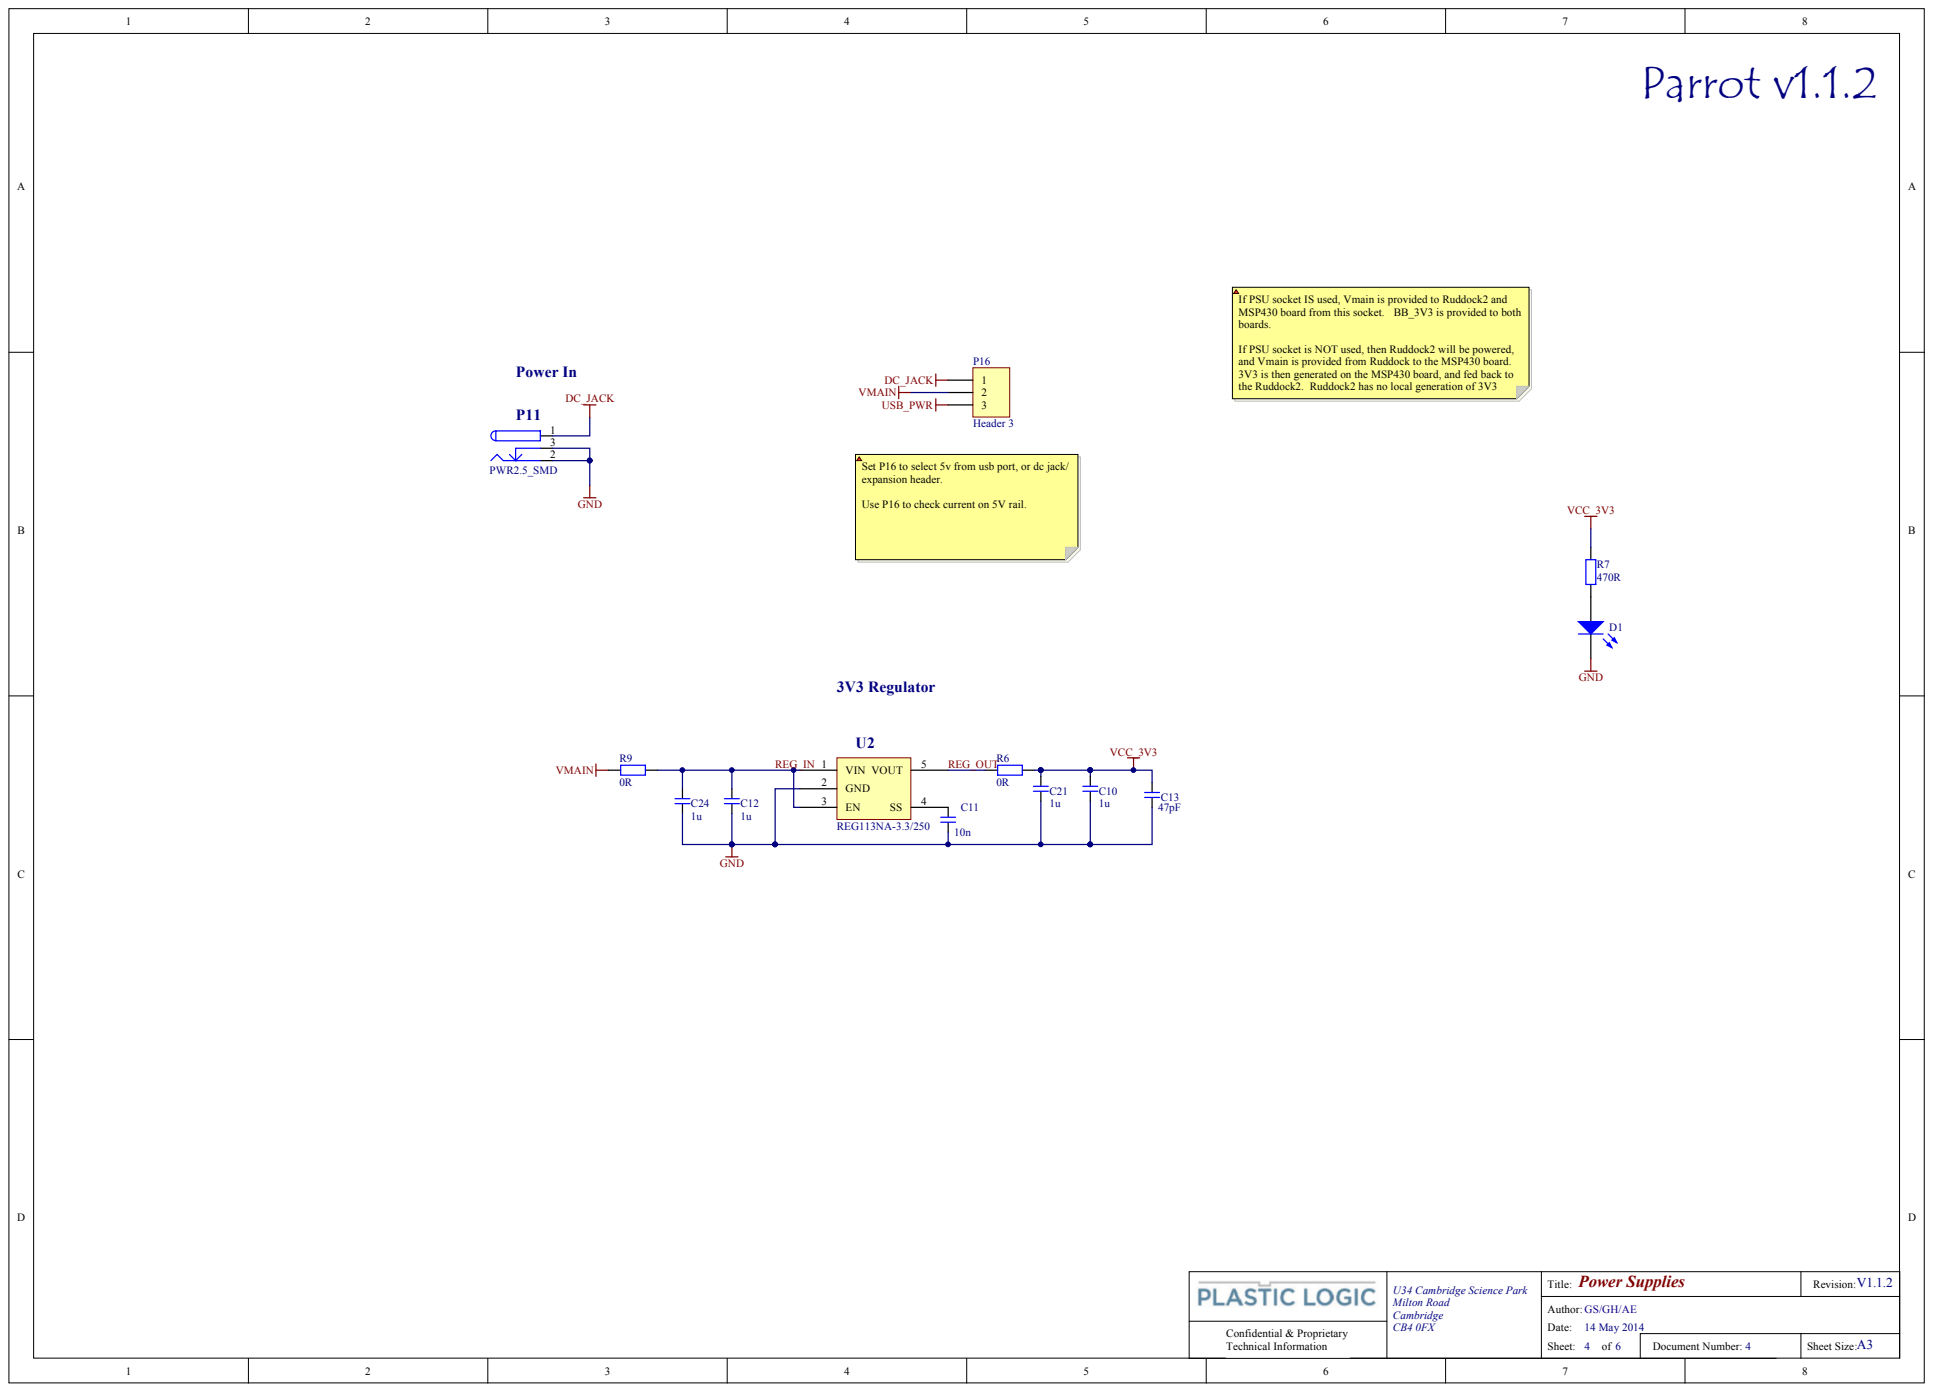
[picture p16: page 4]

If PSU socket IS used,
MSP430 board from
boards.

is provided from Ruddock
then generated on

the MSP430 board, and fed back

Set P16
expansion header. Use P16 to check current on 5V rai

to select 5v from usb port

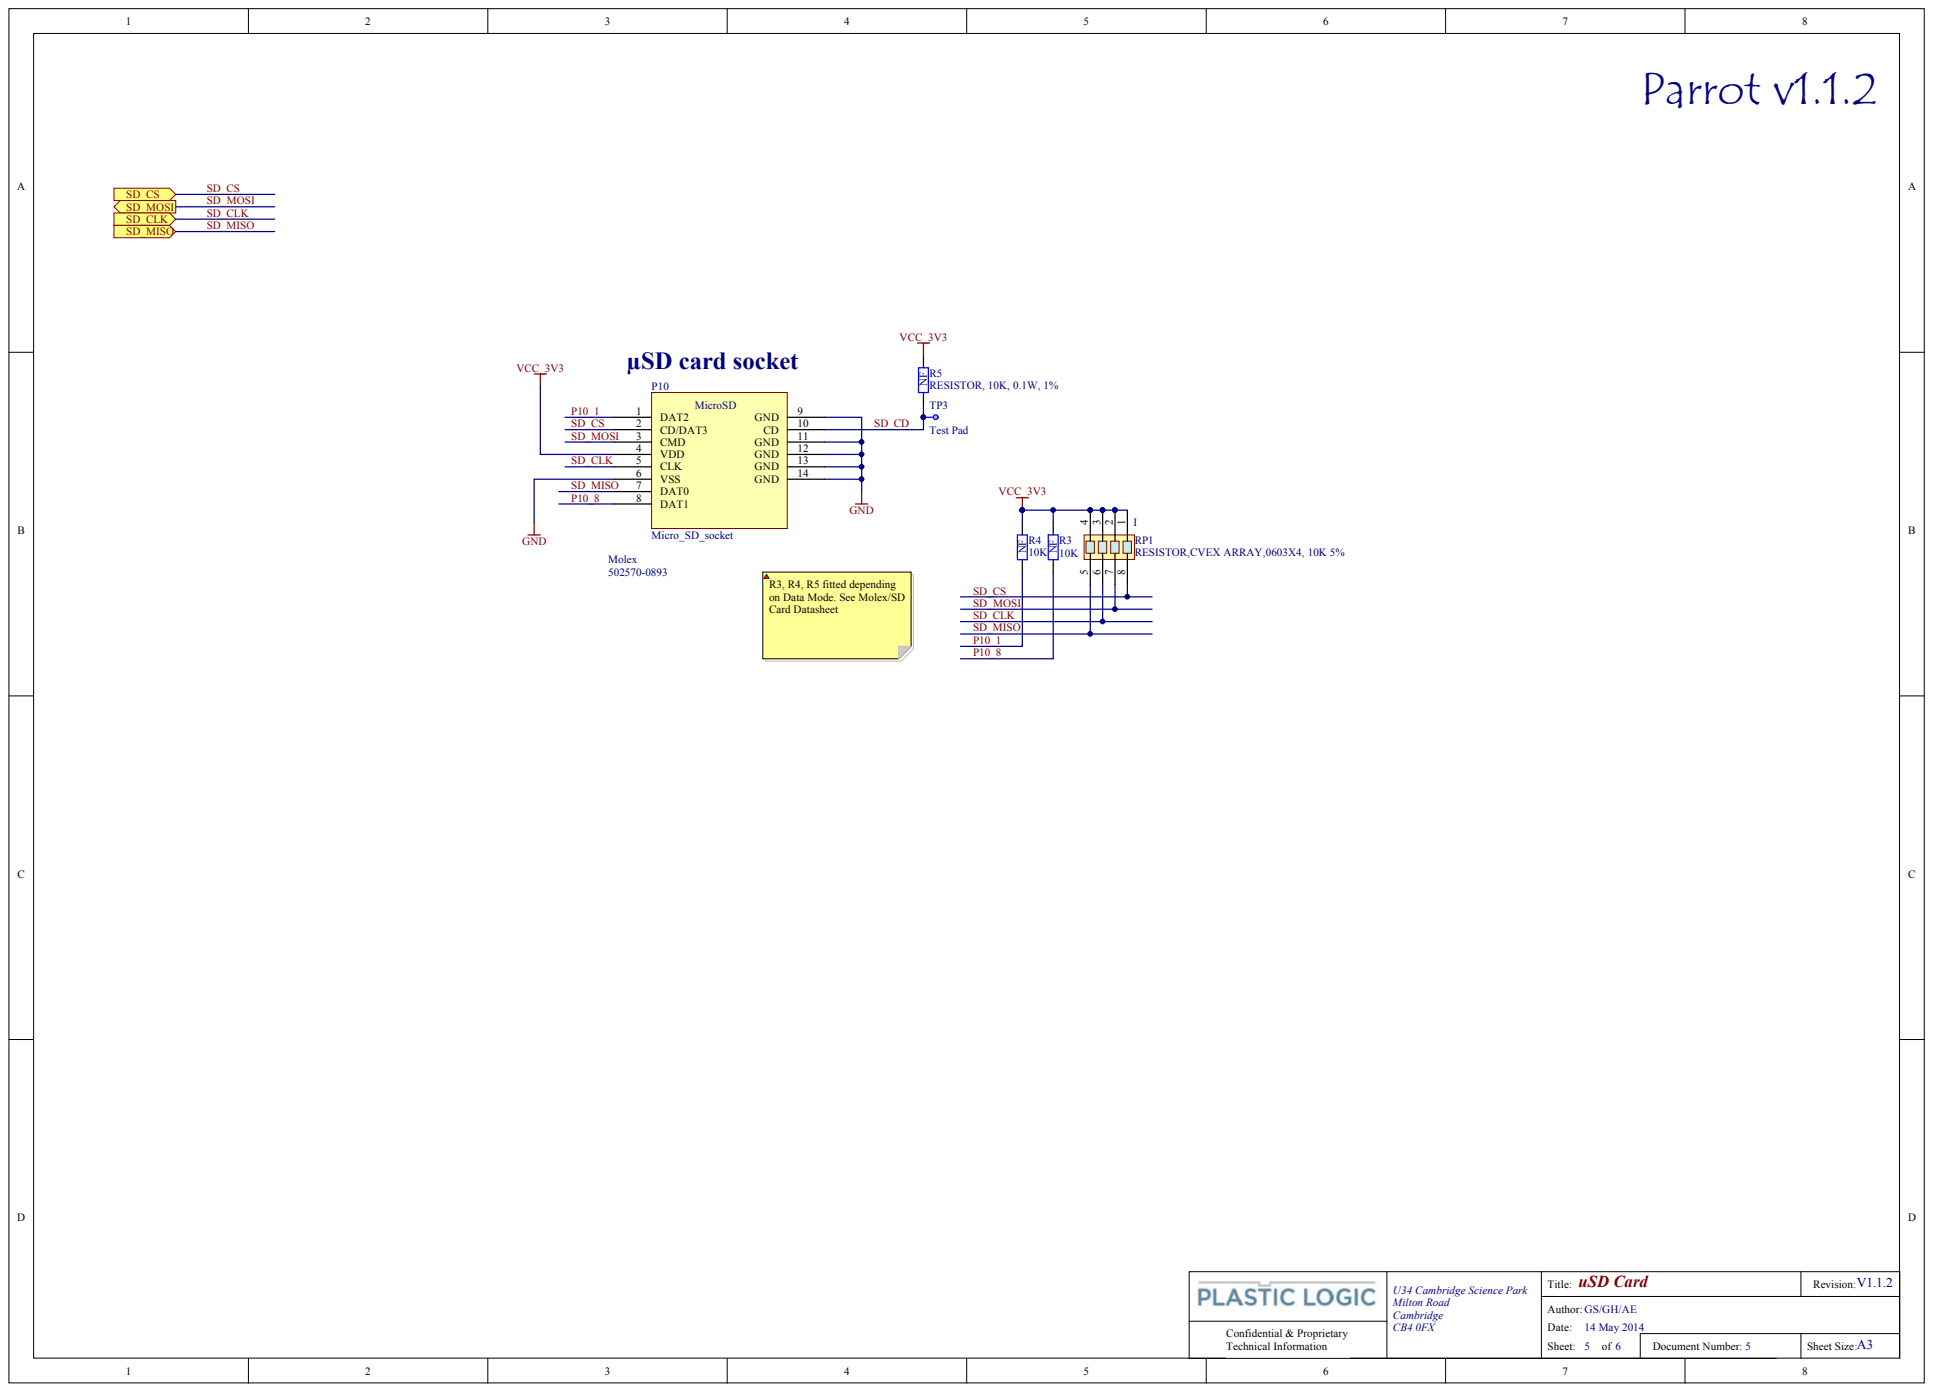
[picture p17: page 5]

Data Mode. See Molex/SD
Card

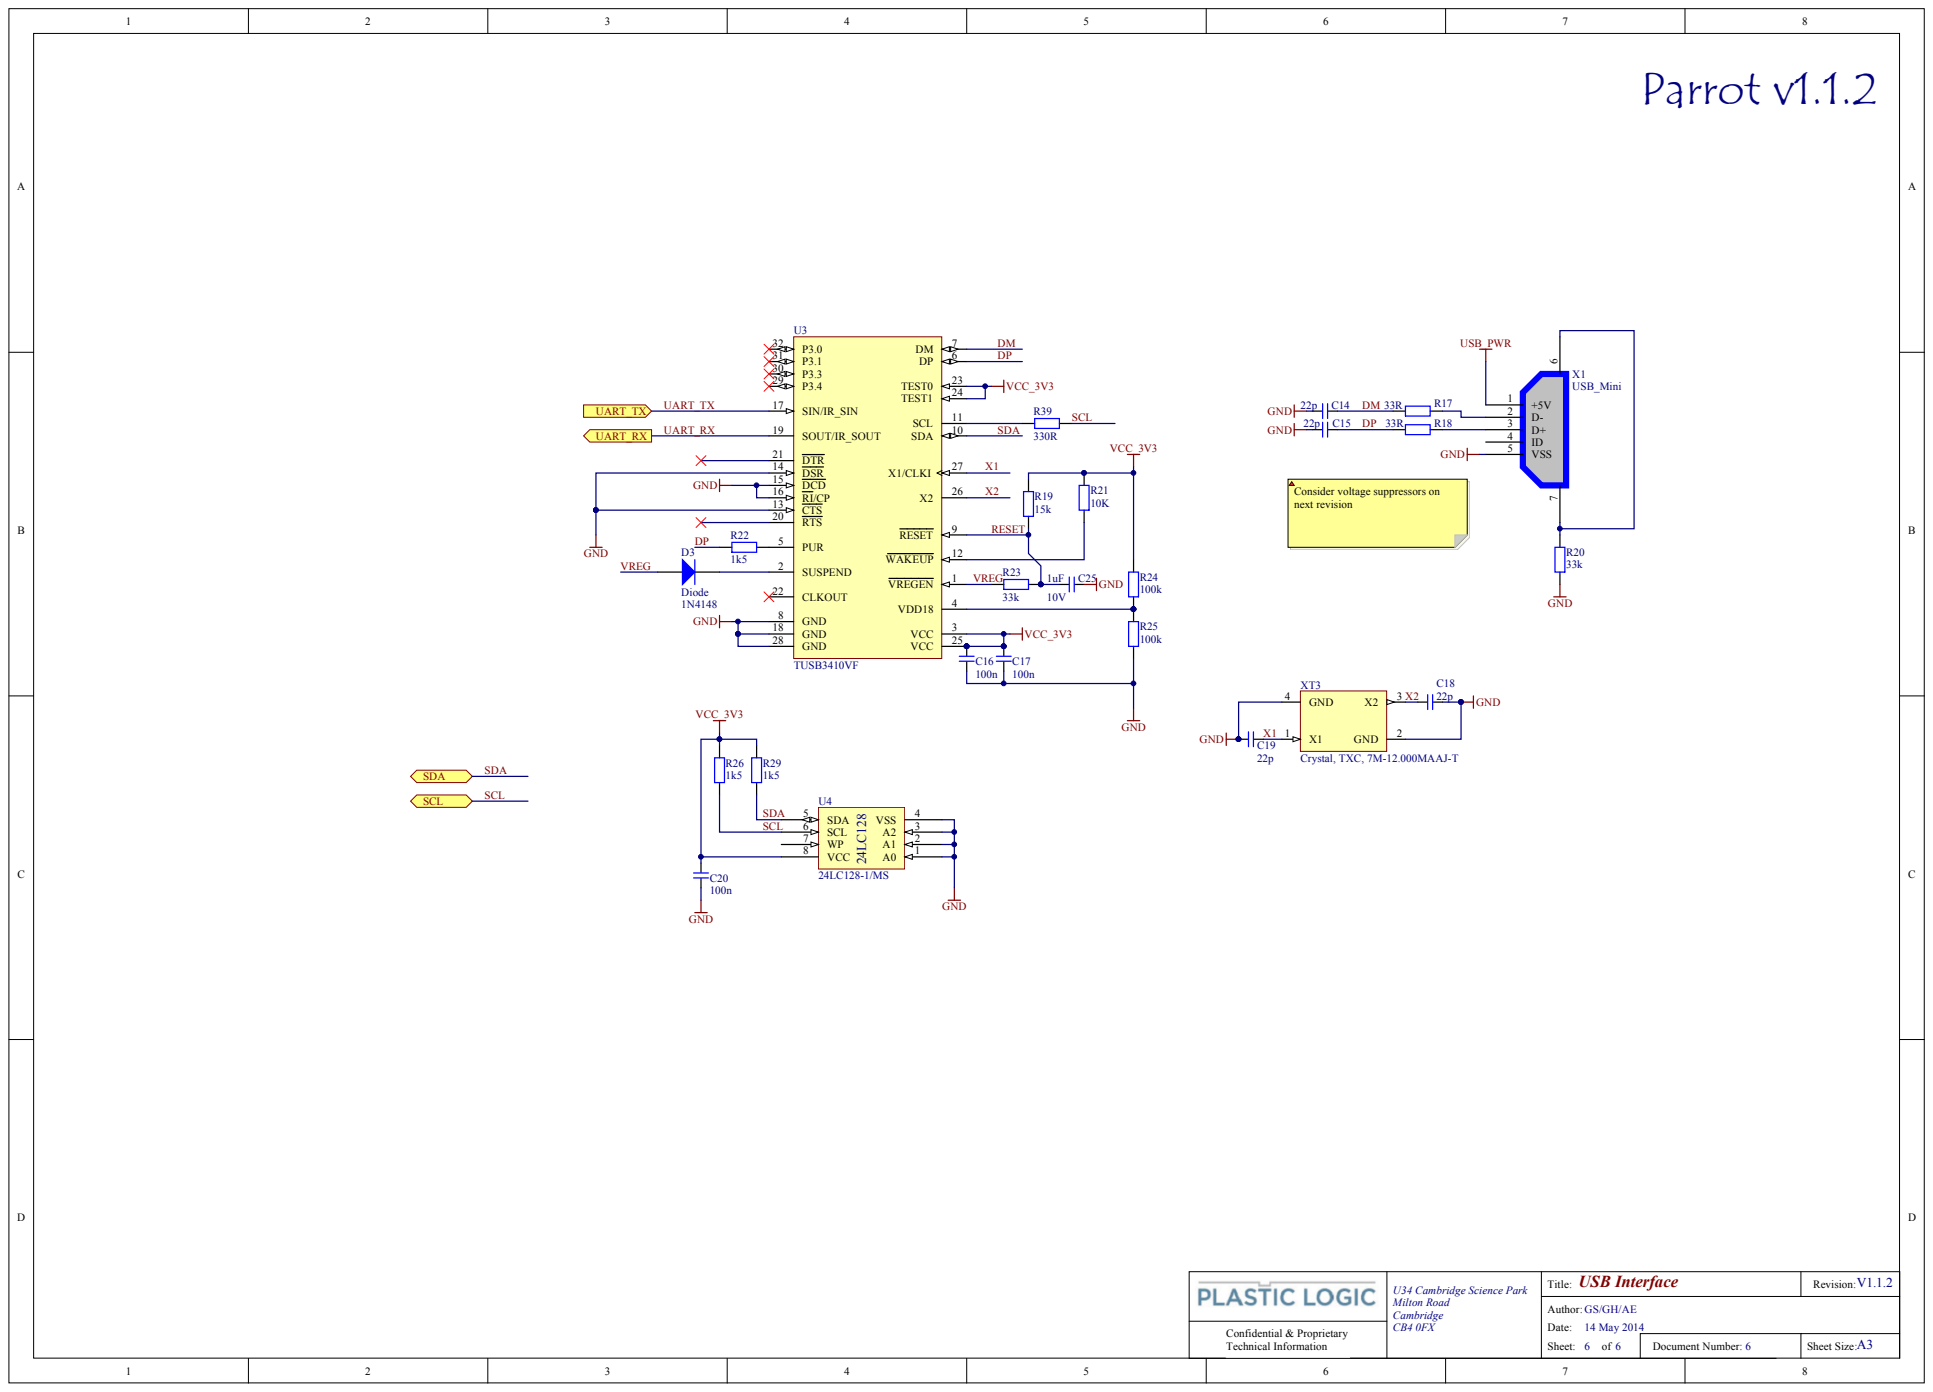
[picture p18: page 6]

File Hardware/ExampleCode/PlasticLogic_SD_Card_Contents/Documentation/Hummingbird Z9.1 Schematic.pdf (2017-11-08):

## Decoupling

## HV Booster

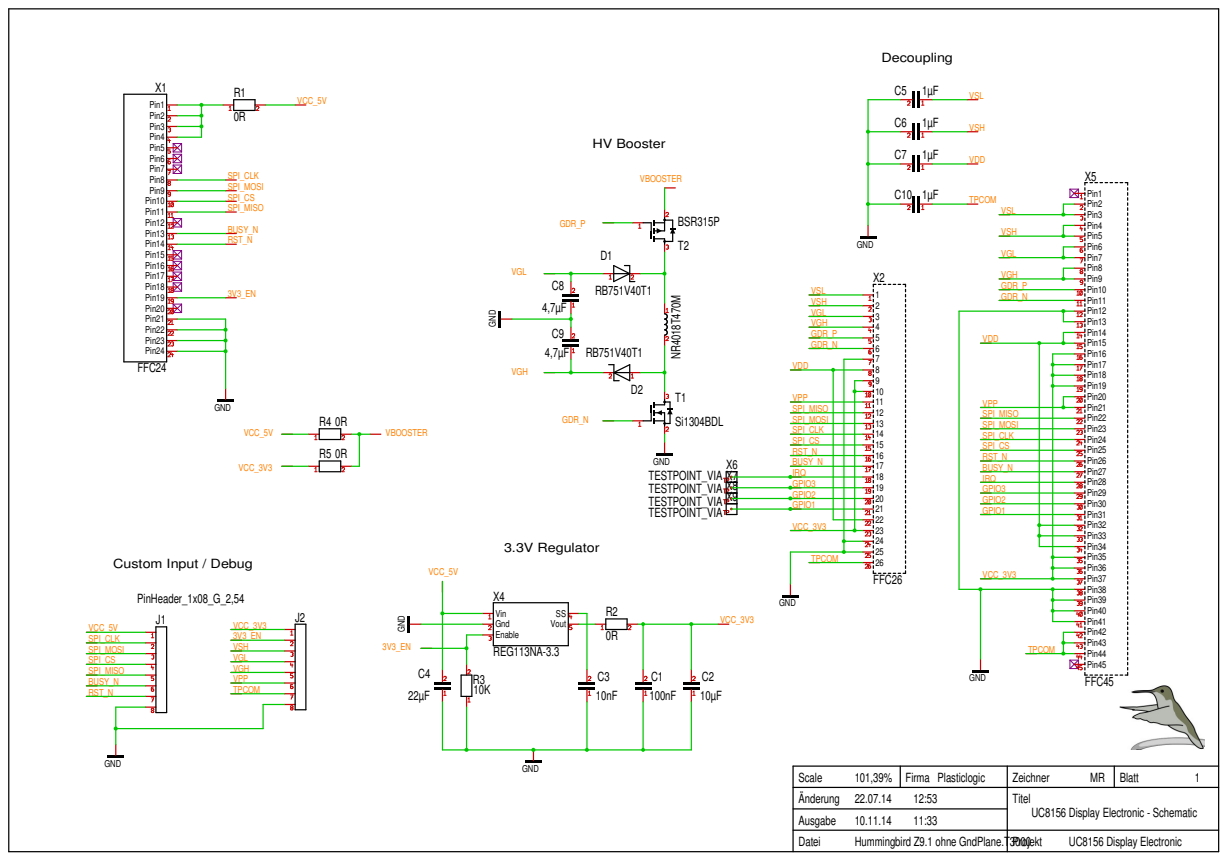
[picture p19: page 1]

Scale 101,39% | Firma Plasticlogic | Zeichner MR | Blatt 1
Änderung 22.07.14 12:53 | | Titel UC8156 Display Electronic - Schematic

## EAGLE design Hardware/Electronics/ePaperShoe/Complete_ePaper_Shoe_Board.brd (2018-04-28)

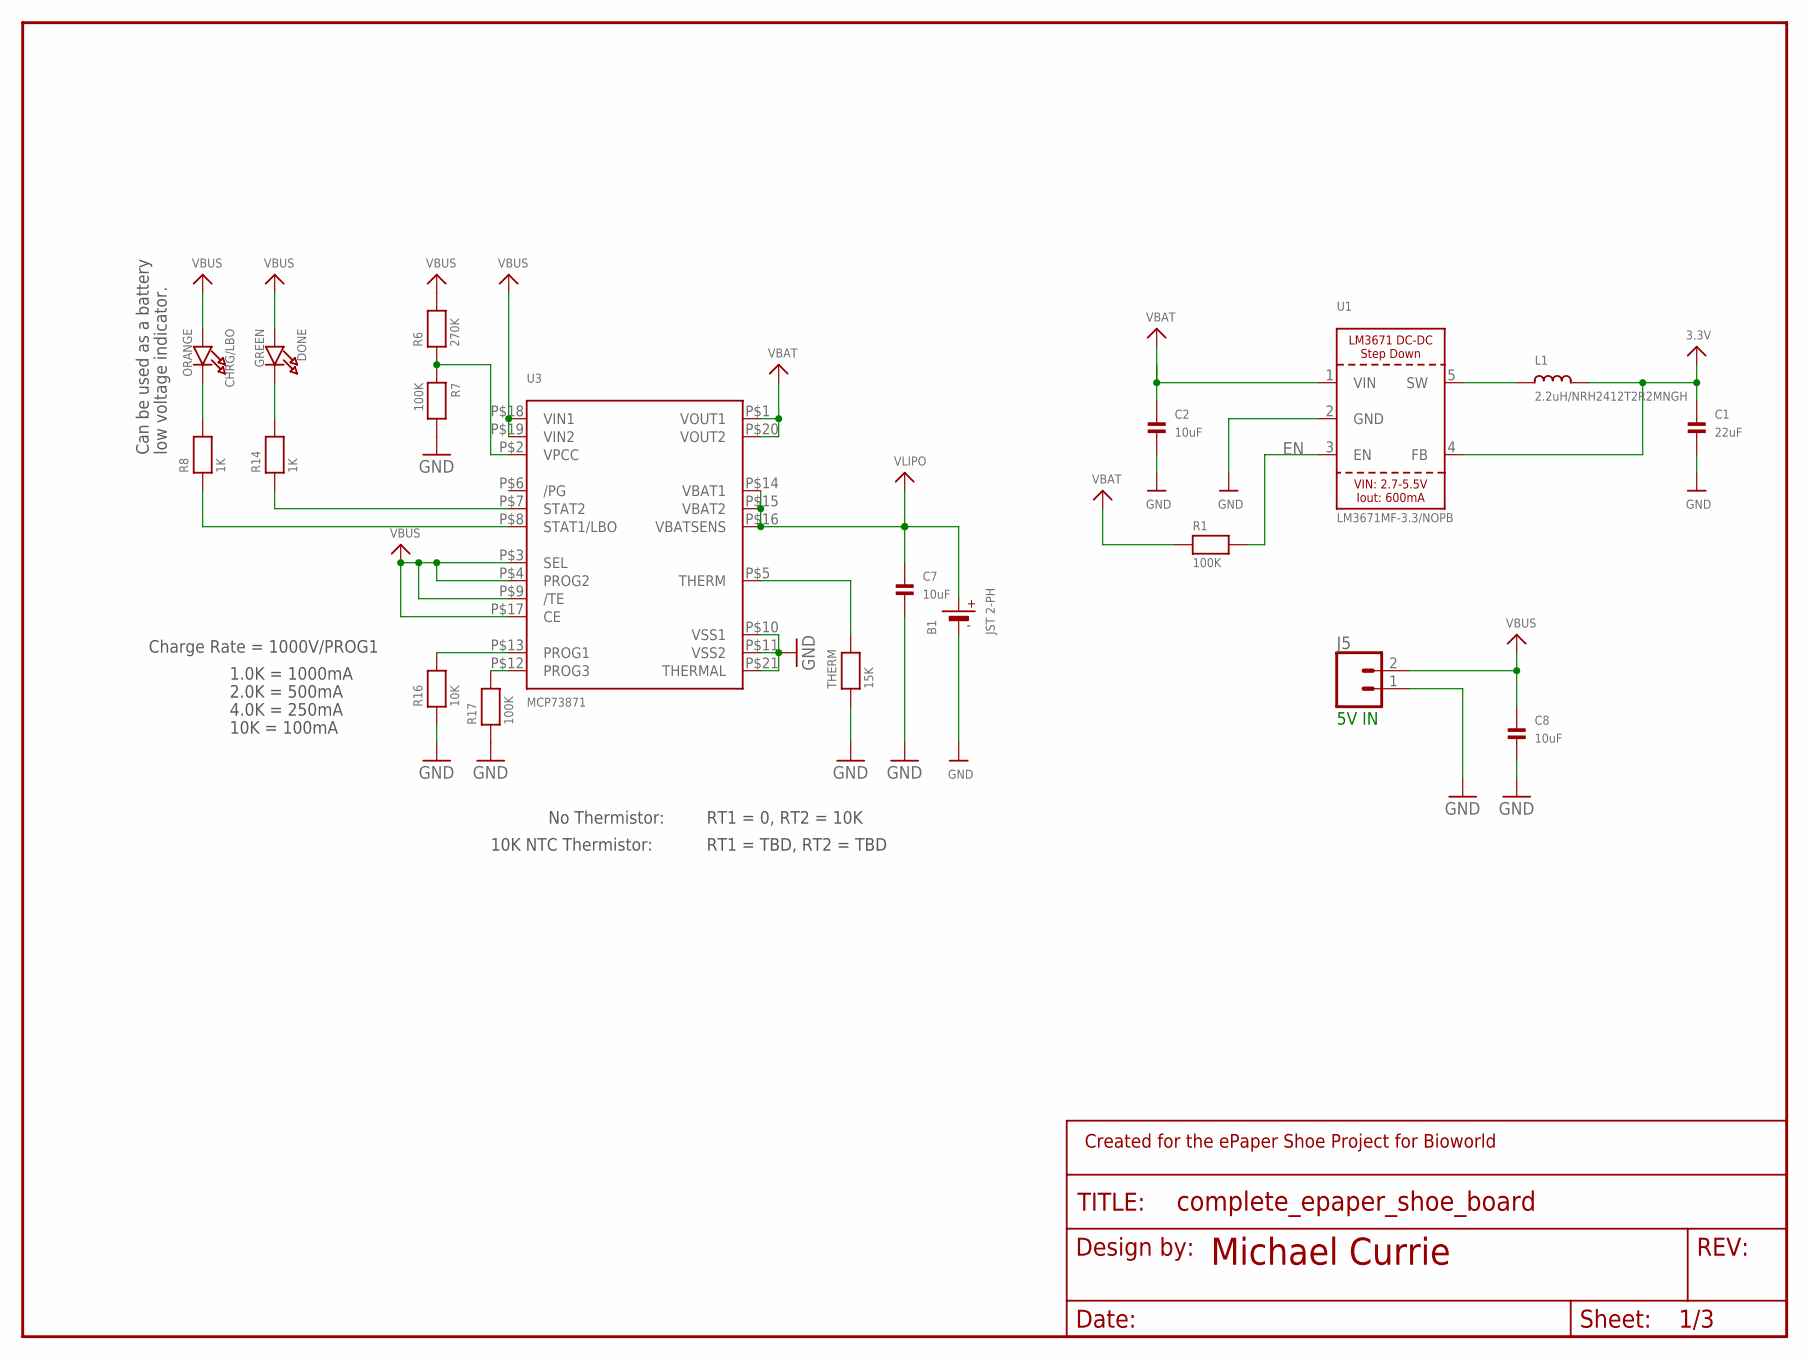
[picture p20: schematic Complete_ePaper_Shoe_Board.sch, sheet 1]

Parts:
B1: JST 2-PH; JSTPH2
C1: 22uF; 0805
C2, C7, C8: 10uF; 0805
CHRG/LBO: ORANGE; CHIPLED_0805_NOOUTLINE
DONE: GREEN; CHIPLED_0805_NOOUTLINE
FRAME1: FRAME-LETTER-MICHAELNO_PACKAGE; DUMMY
J5: CONN_02; 1X02
L1: 2.2uH/NRH2412T2R2MNGH; INDUCTOR_5X5MM_NR5040_NOTHERMALS
R1, R7, R17: 100K; 0805
R6: 270K; 0805
R8, R14: 1K; 0805
R16: 10K; 0805
THERM: 15K; 0805
U1: LM3671MF-3.3/NOPB; SOT23-5
U3: MCP73871; QFN20_4MM

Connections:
3.3V: C1.1, L1.P$2 (2), U1.4 (FB); also elsewhere on the board
EN: R1.2, U1.3 (EN)
GND: B1.1 (-), C1.2, C2.2, C7.2, C8.2, J5.1, R7.2, R16.1, R17.1, THERM.1, U1.2 (GND), U3.P$10 (VSS1), U3.P$11 (VSS2), U3.P$21 (THERMAL); also elsewhere on the board
unnamed: L1.P$1 (1), U1.5 (SW)
unnamed: R6.1, R7.1, U3.P$2 (VPCC)
unnamed: DONE.C, R14.2
unnamed: R14.1, U3.P$7 (STAT2)
unnamed: THERM.2, U3.P$5 (THERM)
unnamed: R8.1, U3.P$8 (STAT1/LBO)
unnamed: CHRG/LBO.C, R8.2
unnamed: R17.2, U3.P$12 (PROG3)
unnamed: R16.2, U3.P$13 (PROG1)
VBAT: C2.1, R1.1, U1.1 (VIN), U3.P$1 (VOUT1), U3.P$20 (VOUT2)
VBUS: C8.1, CHRG/LBO.A, DONE.A, J5.2, R6.2, U3.P$3 (SEL), U3.P$4 (PROG2), U3.P$9 (/TE), U3.P$17 (CE), U3.P$18 (VIN1), U3.P$19 (VIN2)
VLIPO: B1.2 (+), C7.1, U3.P$14 (VBAT1), U3.P$15 (VBAT2), U3.P$16 (VBATSENS)

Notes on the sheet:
Charge Rate = 1000V/PROG1
1.0K = 1000mA
2.0K = 500mA
No Thermistor:
10K NTC Thermistor:
RT1 = 0, RT2 = 10K
RT1 = TBD, RT2 = TBD
4.0K = 250mA
10K = 100mA
Can be used as a battery
low voltage indicator.
5V IN

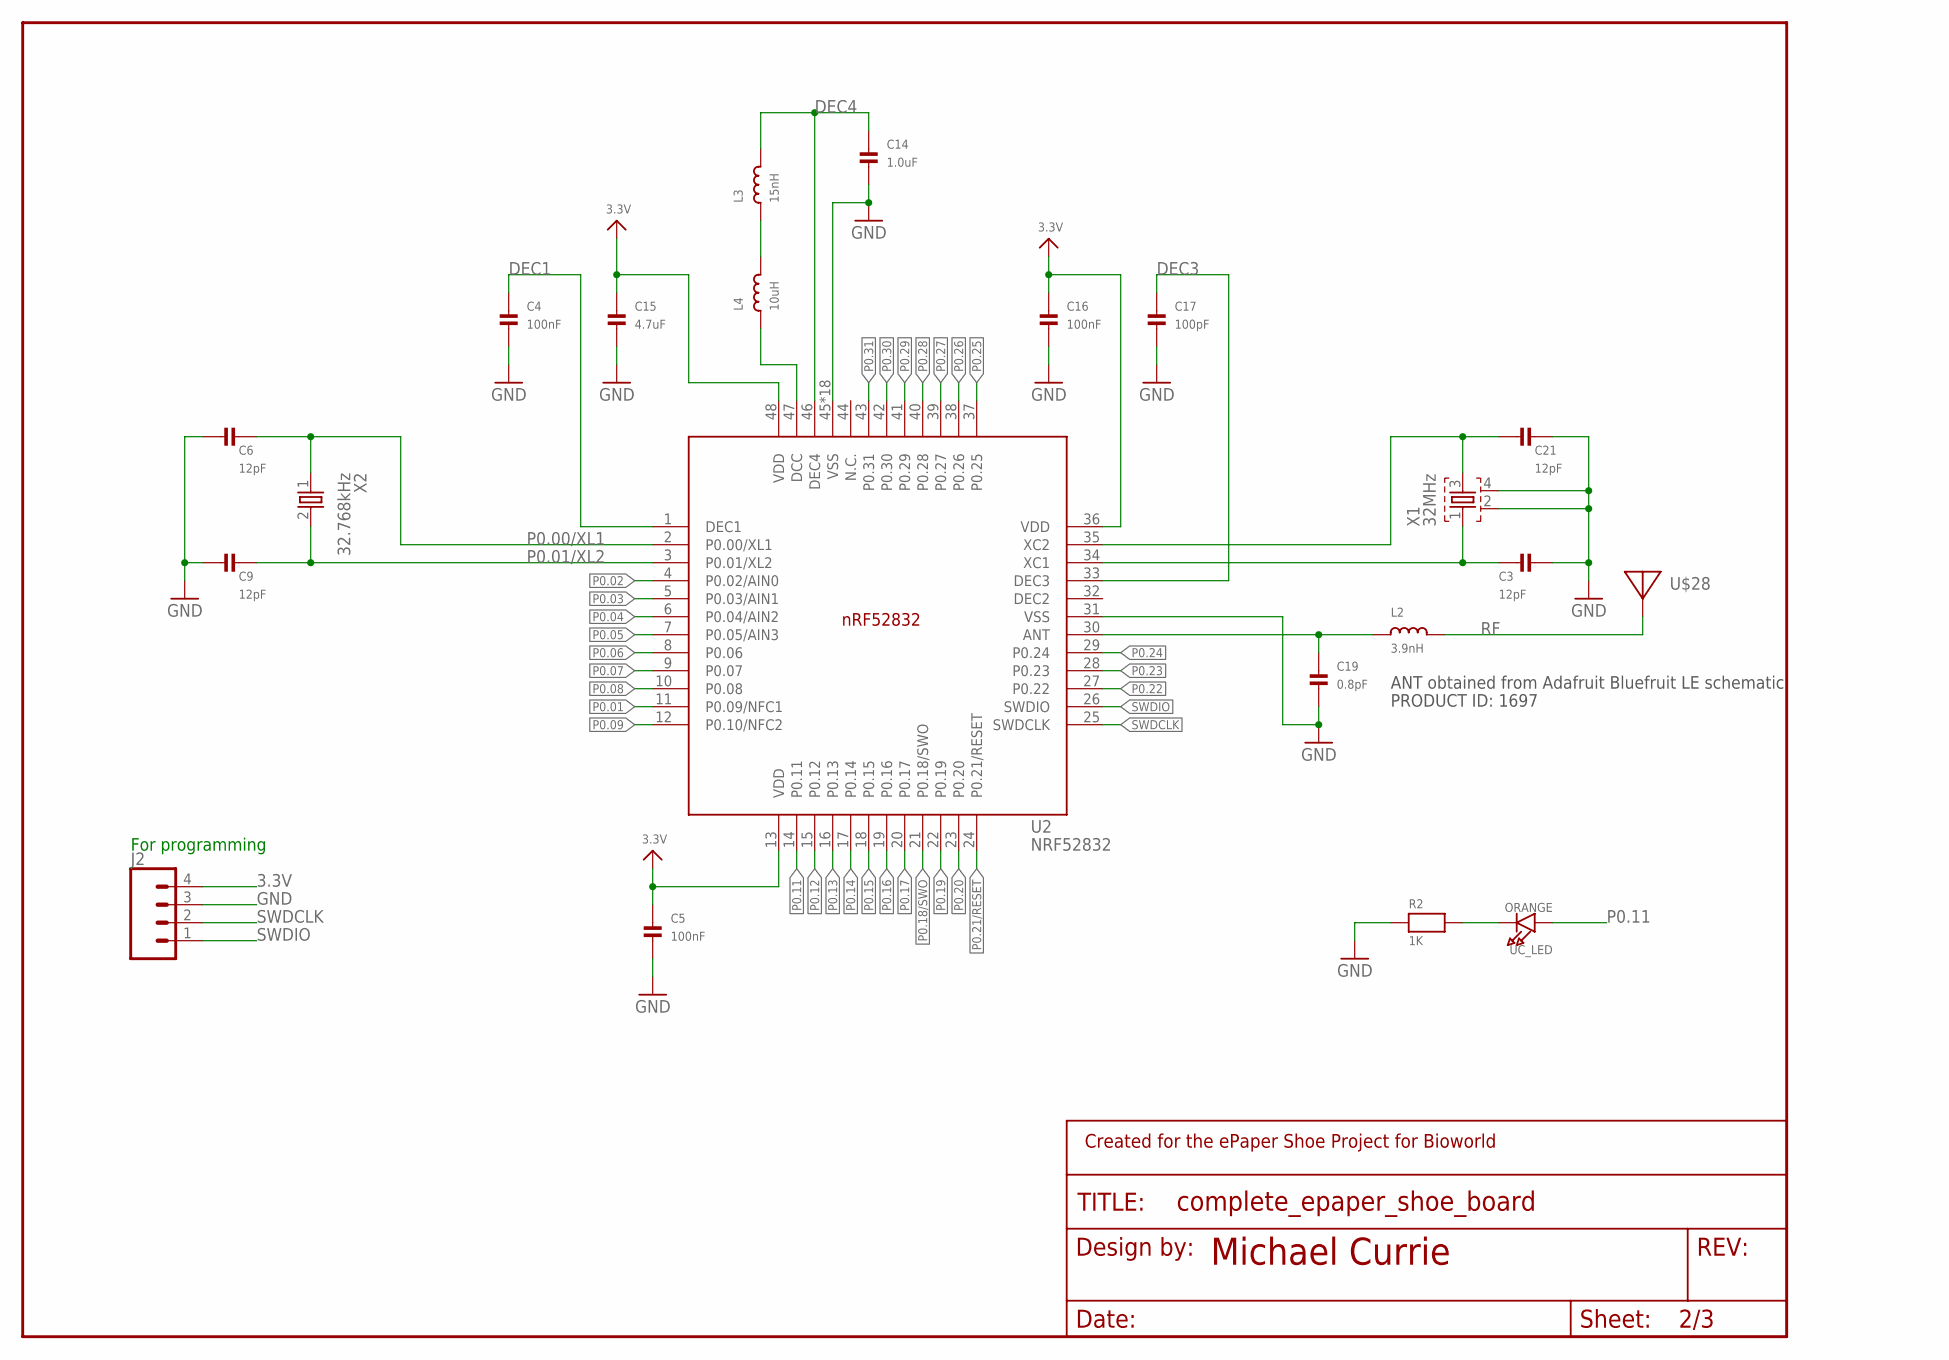
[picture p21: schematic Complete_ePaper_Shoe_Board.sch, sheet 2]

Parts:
C3, C6, C9, C21: 12pF; 0805
C4, C5, C16: 100nF; 0805
C14: 1.0uF; 0805
C15: 4.7uF; 0805
C17: 100pF; 0805
C19: 0.8pF; 0805
FRAME2: FRAME-LETTER-MICHAELNO_PACKAGE; DUMMY
J2: CONN_04; 1X04
L2: 3.9nH; 0805
L3: 15nH; 0805
L4: 10uH; 0805
R2: 1K; 0805
U2: NRF52832; QFN40P600X600X90-48_N
U$28: ANTENNA_PCBNRF8001_1.6MM; ANT_PCB_2.4GHZ_NRF8001_1.6MM_1OZ
UC_LED: ORANGE; CHIPLED_0805_NOOUTLINE
X1: 32MHz; BT-XTAL_2016_N
X2: 32.768kHz; XTAL_3215_N

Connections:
3.3V: C5.1, C15.1, C16.1, J2.4, U2.13 (VDD), U2.36 (VDD), U2.48 (VDD); also elsewhere on the board
ANT: C19.1, L2.1, U2.30 (ANT)
DEC1: C4.1, U2.1 (DEC1)
DEC3: C17.1, U2.33 (DEC3)
DEC4: C14.1, L3.2, U2.46 (DEC4)
GND: C3.2, C4.2, C5.2, C6.1, C9.1, C14.2, C15.2, C16.2, C17.2, C19.2, C21.2, J2.3, R2.1, U2.31 (VSS), U2.45 (VSS), U2.PAD (VSS), U2.PAD@VIA01 (VSS), U2.PAD@VIA02 (VSS), U2.PAD@VIA03 (VSS), U2.PAD@VIA04 (VSS), U2.PAD@VIA05 (VSS), U2.PAD@VIA06 (VSS), U2.PAD@VIA07 (VSS), U2.PAD@VIA08 (VSS), U2.PAD@VIA09 (VSS), U2.PAD@VIA10 (VSS), U2.PAD@VIA11 (VSS), U2.PAD@VIA12 (VSS), U2.PAD@VIA13 (VSS), U2.PAD@VIA14 (VSS), U2.PAD@VIA15 (VSS), U2.PAD@VIA16 (VSS), X1.2, X1.4; also elsewhere on the board
unnamed: L3.1, L4.2
unnamed: C21.1, U2.35 (XC2), X1.3
unnamed: L4.1, U2.47 (DCC)
unnamed: R2.2, UC_LED.C
P0.00/XL1: C6.2, U2.2 (P0.00/XL1), X2.1
P0.01: U2.11 (P0.09/NFC1)
P0.01/XL2: C9.2, U2.3 (P0.01/XL2), X2.2
P0.02: U2.4 (P0.02/AIN0)
P0.03: U2.5 (P0.03/AIN1)
P0.04: U2.6 (P0.04/AIN2)
P0.05: U2.7 (P0.05/AIN3)
P0.06: U2.8 (P0.06)
P0.07: U2.9 (P0.07)
P0.08: U2.10 (P0.08)
P0.09: U2.12 (P0.10/NFC2)
P0.11: U2.14 (P0.11), UC_LED.A
P0.12: U2.15 (P0.12)
P0.13: U2.16 (P0.13)
P0.14: U2.17 (P0.14)
P0.15: U2.18 (P0.15)
P0.16: U2.19 (P0.16)
P0.17: U2.20 (P0.17)
P0.18/SWO: U2.21 (P0.18/SWO)
P0.19: U2.22 (P0.19)
P0.20: U2.23 (P0.20)
P0.21/RESET: U2.24 (P0.21/RESET)
P0.22: U2.27 (P0.22); also elsewhere on the board
P0.23: U2.28 (P0.23); also elsewhere on the board
P0.24: U2.29 (P0.24); also elsewhere on the board
P0.25: U2.37 (P0.25); also elsewhere on the board
P0.26: U2.38 (P0.26)
P0.27: U2.39 (P0.27)
P0.28: U2.40 (P0.28)
P0.29: U2.41 (P0.29)
P0.30: U2.42 (P0.30); also elsewhere on the board
P0.31: U2.43 (P0.31); also elsewhere on the board
RF: L2.2, U$28.FEED
SWDCLK: J2.2, U2.25 (SWDCLK)
SWDIO: J2.1, U2.26 (SWDIO)
X1: C3.1, U2.34 (XC1), X1.1

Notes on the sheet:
ANT obtained from Adafruit Bluefruit LE schematic
PRODUCT ID: 1697
For programming

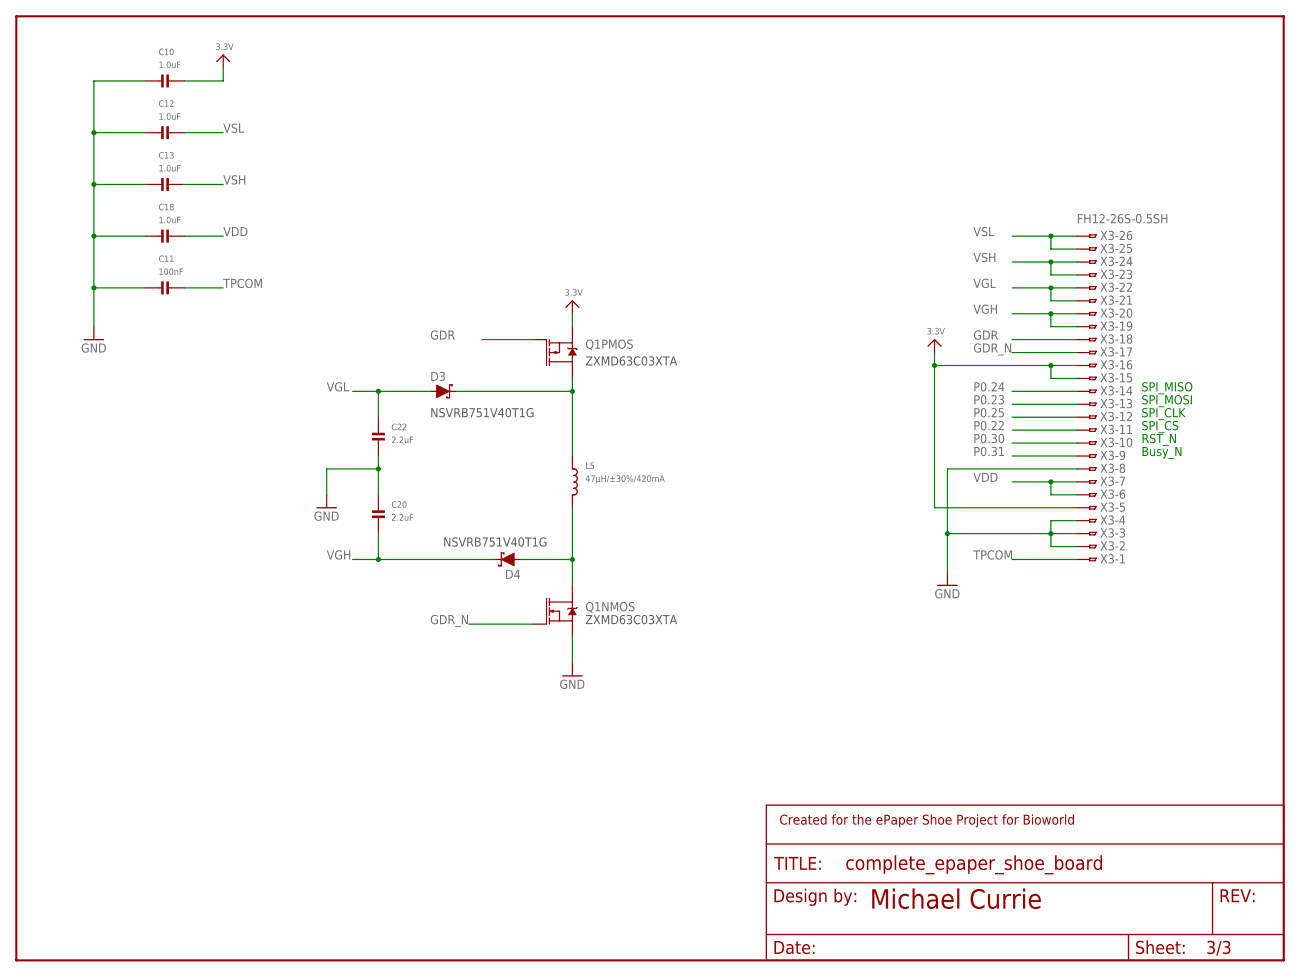
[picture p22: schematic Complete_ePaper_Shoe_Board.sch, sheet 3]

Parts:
C10, C12, C13, C18: 1.0uF; 0805
C11: 100nF; 0805
C20, C22: 2.2uF; 0805
D3, D4: 0.5A/40V/420mV; SOD-323
FRAME3: FRAME-LETTER-MICHAELNO_PACKAGE; DUMMY
L5: 47µH/±30%/420mA; INDUCTOR_5X5MM_NR5040_NOTHERMALS
Q1: IRF7509; MSOP8
X3: FH12-26S-0.5SH

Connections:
3.3V: C10.2, Q1.3 (S), X3.5, X3.15, X3.16; also elsewhere on the board
GDR: Q1.4 (G), X3.18
GDR_N: Q1.2 (G), X3.17
GND: C10.1, C11.1, C12.1, C13.1, C18.1, C20.1, C22.2, Q1.1 (S), X3.2, X3.3, X3.4, X3.8; also elsewhere on the board
unnamed: D3.C, L5.P$1 (1), Q1.5 (D), Q1.6 (D)
unnamed: D4.A, L5.P$2 (2), Q1.7 (D), Q1.8 (D)
P0.22: X3.11; also elsewhere on the board
P0.23: X3.13; also elsewhere on the board
P0.24: X3.14; also elsewhere on the board
P0.25: X3.12; also elsewhere on the board
P0.30: X3.10; also elsewhere on the board
P0.31: X3.9; also elsewhere on the board
TPCOM: C11.2, X3.1
VDD: C18.2, X3.6, X3.7
VGH: C20.2, D4.C, X3.19, X3.20
VGL: C22.1, D3.A, X3.21, X3.22
VSH: C13.2, X3.23, X3.24
VSL: C12.2, X3.25, X3.26

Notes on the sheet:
ZXMD63C03XTA
NSVRB751V40T1G
SPI_CLK
SPI_MOSI
SPI_CS
SPI_MISO
Busy_N
RST_N

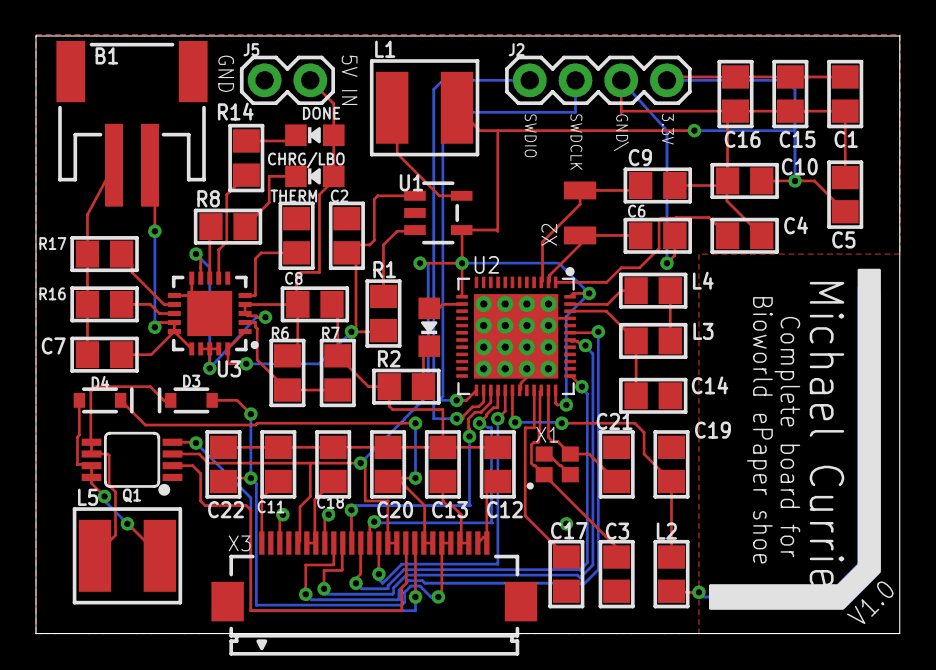
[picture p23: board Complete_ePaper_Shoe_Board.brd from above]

Board: 2 copper layers, 48.0 x 33.2 mm, 55 parts (1 on the bottom side), 46 nets.

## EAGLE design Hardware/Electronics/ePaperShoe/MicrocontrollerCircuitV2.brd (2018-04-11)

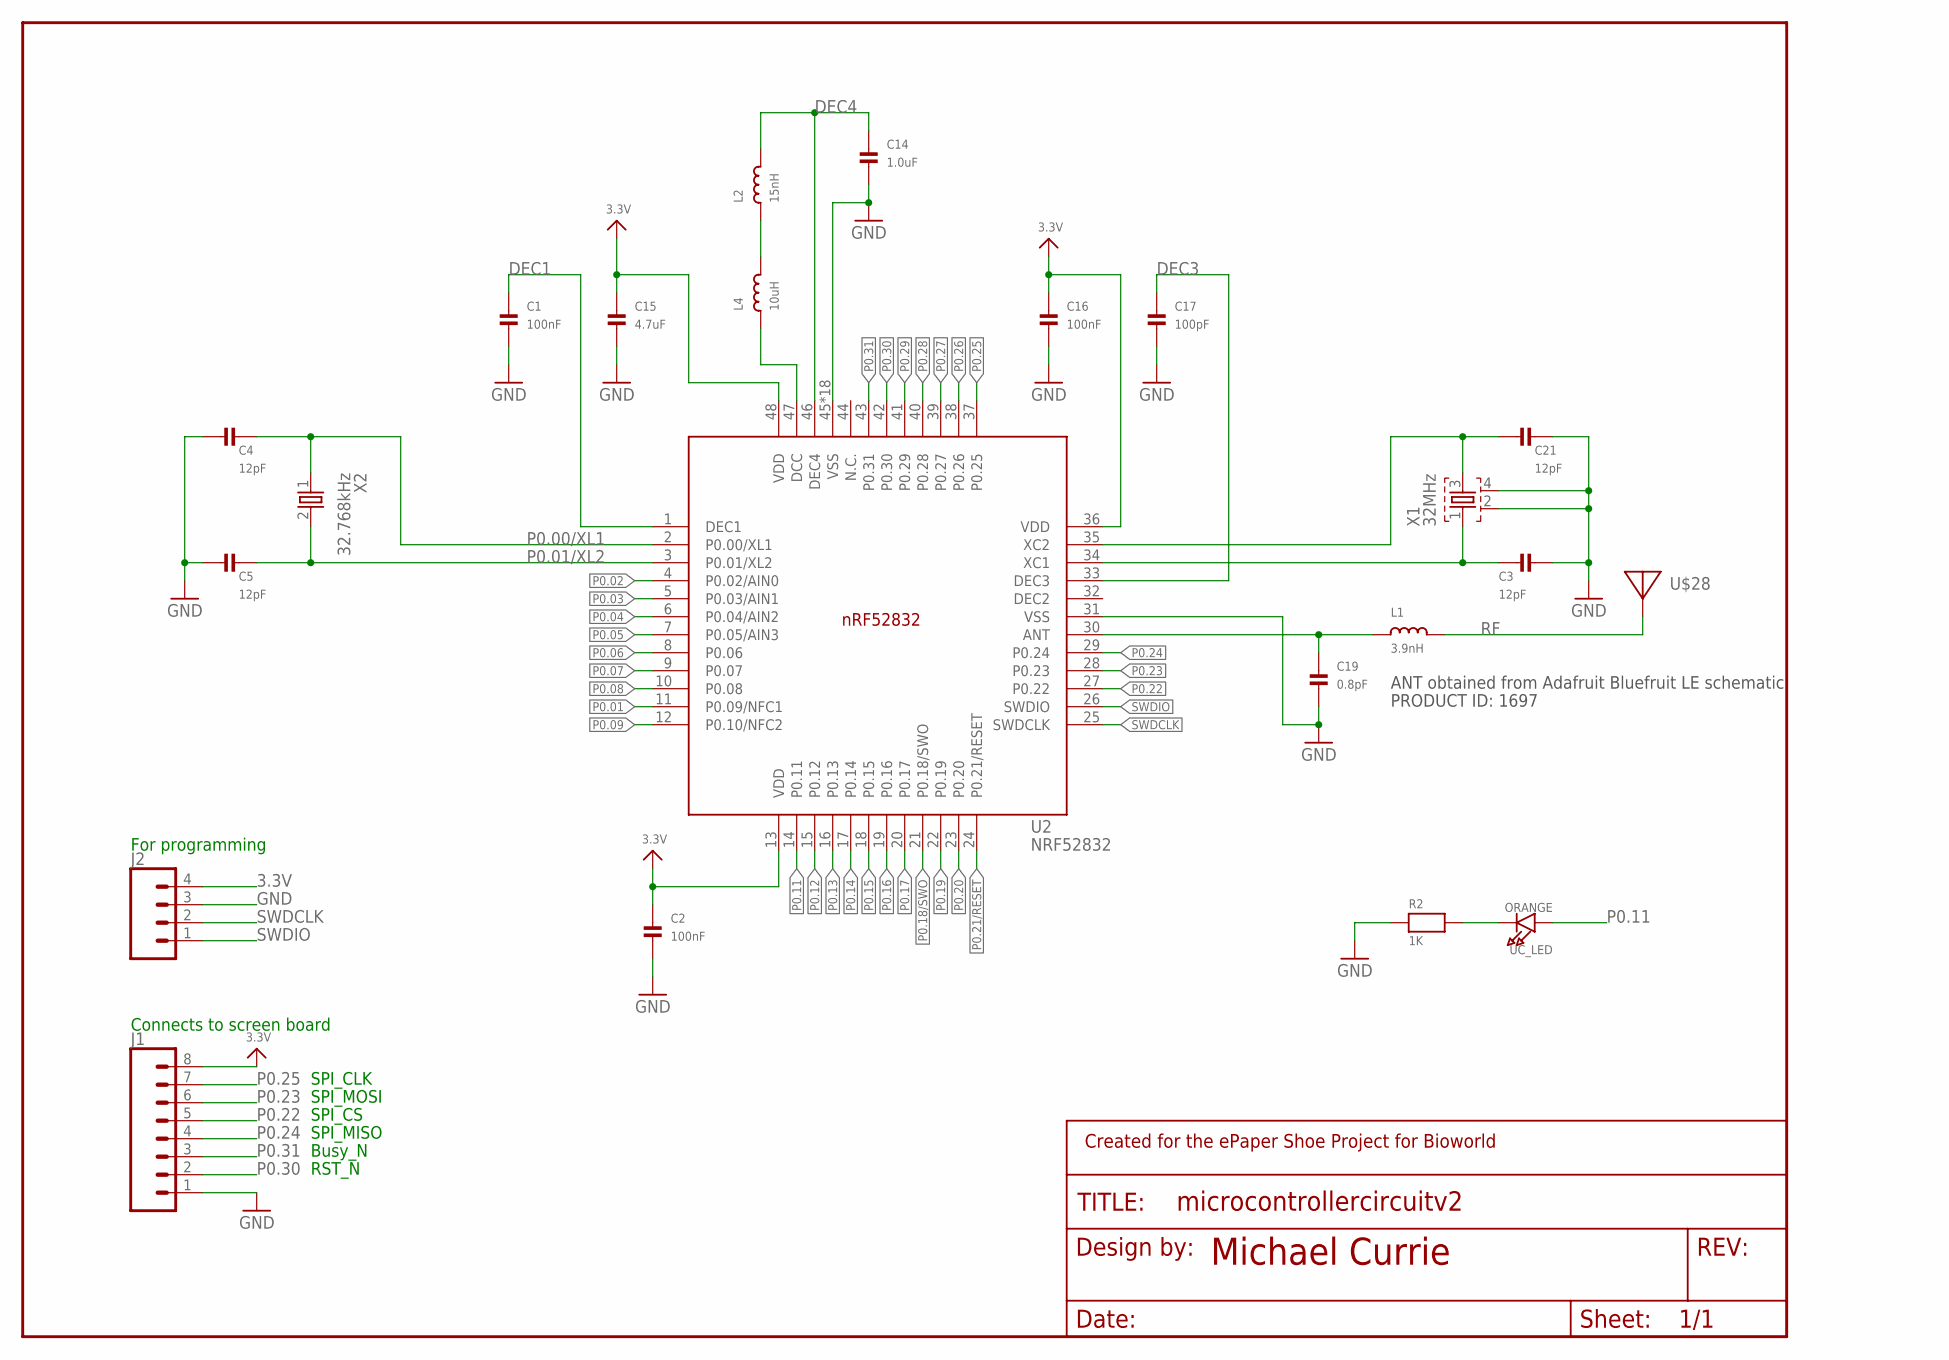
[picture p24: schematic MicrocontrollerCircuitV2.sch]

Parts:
C1, C2, C16: 100nF; 0805
C3, C4, C5, C21: 12pF; 0805
C14: 1.0uF; 0805
C15: 4.7uF; 0805
C17: 100pF; 0805
C19: 0.8pF; 0805
FRAME2: FRAME-LETTER-MICHAELNO_PACKAGE; DUMMY
J1: CONN_08"; 1X08
J2: CONN_04; 1X04
L1: 3.9nH; 0805
L2: 15nH; 0805
L4: 10uH; 0805
R2: 1K; 0805
U2: NRF52832; QFN40P600X600X90-48_N
U$28: ANTENNA_PCBNRF8001_1.6MM; ANT_PCB_2.4GHZ_NRF8001_1.6MM_1OZ
UC_LED: ORANGE; CHIPLED_0805_NOOUTLINE
X1: 32MHz; BT-XTAL_2016_N
X2: 32.768kHz; XTAL_3215_N

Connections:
3.3V: C2.1, C15.1, C16.1, J1.8, J2.4, U2.13 (VDD), U2.36 (VDD), U2.48 (VDD)
ANT: C19.1, L1.1, U2.30 (ANT)
DEC1: C1.1, U2.1 (DEC1)
DEC3: C17.1, U2.33 (DEC3)
DEC4: C14.1, L2.2, U2.46 (DEC4)
GND: C1.2, C2.2, C3.2, C4.1, C5.1, C14.2, C15.2, C16.2, C17.2, C19.2, C21.2, J1.1, J2.3, R2.1, U2.31 (VSS), U2.45 (VSS), U2.PAD (VSS), U2.PAD@VIA01 (VSS), U2.PAD@VIA02 (VSS), U2.PAD@VIA03 (VSS), U2.PAD@VIA04 (VSS), U2.PAD@VIA05 (VSS), U2.PAD@VIA06 (VSS), U2.PAD@VIA07 (VSS), U2.PAD@VIA08 (VSS), U2.PAD@VIA09 (VSS), U2.PAD@VIA10 (VSS), U2.PAD@VIA11 (VSS), U2.PAD@VIA12 (VSS), U2.PAD@VIA13 (VSS), U2.PAD@VIA14 (VSS), U2.PAD@VIA15 (VSS), U2.PAD@VIA16 (VSS), X1.2, X1.4
unnamed: L2.1, L4.2
unnamed: C21.1, U2.35 (XC2), X1.3
unnamed: L4.1, U2.47 (DCC)
unnamed: R2.2, UC_LED.C
P0.00/XL1: C4.2, U2.2 (P0.00/XL1), X2.1
P0.01: U2.11 (P0.09/NFC1)
P0.01/XL2: C5.2, U2.3 (P0.01/XL2), X2.2
P0.02: U2.4 (P0.02/AIN0)
P0.03: U2.5 (P0.03/AIN1)
P0.04: U2.6 (P0.04/AIN2)
P0.05: U2.7 (P0.05/AIN3)
P0.06: U2.8 (P0.06)
P0.07: U2.9 (P0.07)
P0.08: U2.10 (P0.08)
P0.09: U2.12 (P0.10/NFC2)
P0.11: U2.14 (P0.11), UC_LED.A
P0.12: U2.15 (P0.12)
P0.13: U2.16 (P0.13)
P0.14: U2.17 (P0.14)
P0.15: U2.18 (P0.15)
P0.16: U2.19 (P0.16)
P0.17: U2.20 (P0.17)
P0.18/SWO: U2.21 (P0.18/SWO)
P0.19: U2.22 (P0.19)
P0.20: U2.23 (P0.20)
P0.21/RESET: U2.24 (P0.21/RESET)
P0.22: J1.5, U2.27 (P0.22)
P0.23: J1.6, U2.28 (P0.23)
P0.24: J1.4, U2.29 (P0.24)
P0.25: J1.7, U2.37 (P0.25)
P0.26: U2.38 (P0.26)
P0.27: U2.39 (P0.27)
P0.28: U2.40 (P0.28)
P0.29: U2.41 (P0.29)
P0.30: J1.2, U2.42 (P0.30)
P0.31: J1.3, U2.43 (P0.31)
RF: L1.2, U$28.FEED
SWDCLK: J2.2, U2.25 (SWDCLK)
SWDIO: J2.1, U2.26 (SWDIO)
X1: C3.1, U2.34 (XC1), X1.1

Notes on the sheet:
ANT obtained from Adafruit Bluefruit LE schematic
PRODUCT ID: 1697
For programming
Connects to screen board
SPI_CLK
SPI_MOSI
SPI_CS
SPI_MISO
Busy_N
RST_N

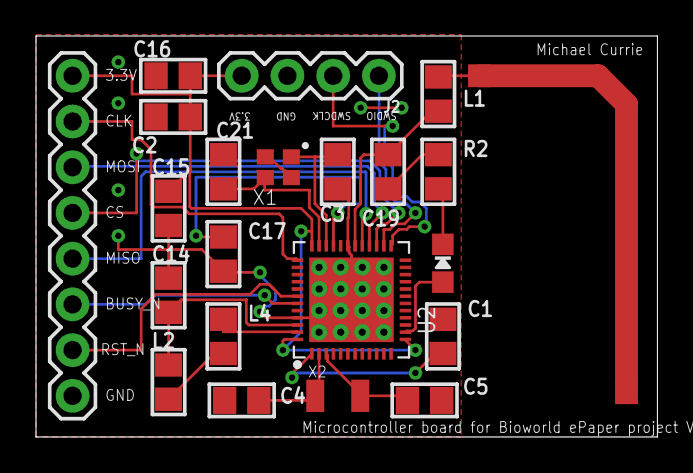
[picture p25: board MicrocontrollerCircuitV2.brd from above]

Board: 2 copper layers, 34.5 x 22.3 mm, 23 parts (0 on the bottom side), 23 nets.

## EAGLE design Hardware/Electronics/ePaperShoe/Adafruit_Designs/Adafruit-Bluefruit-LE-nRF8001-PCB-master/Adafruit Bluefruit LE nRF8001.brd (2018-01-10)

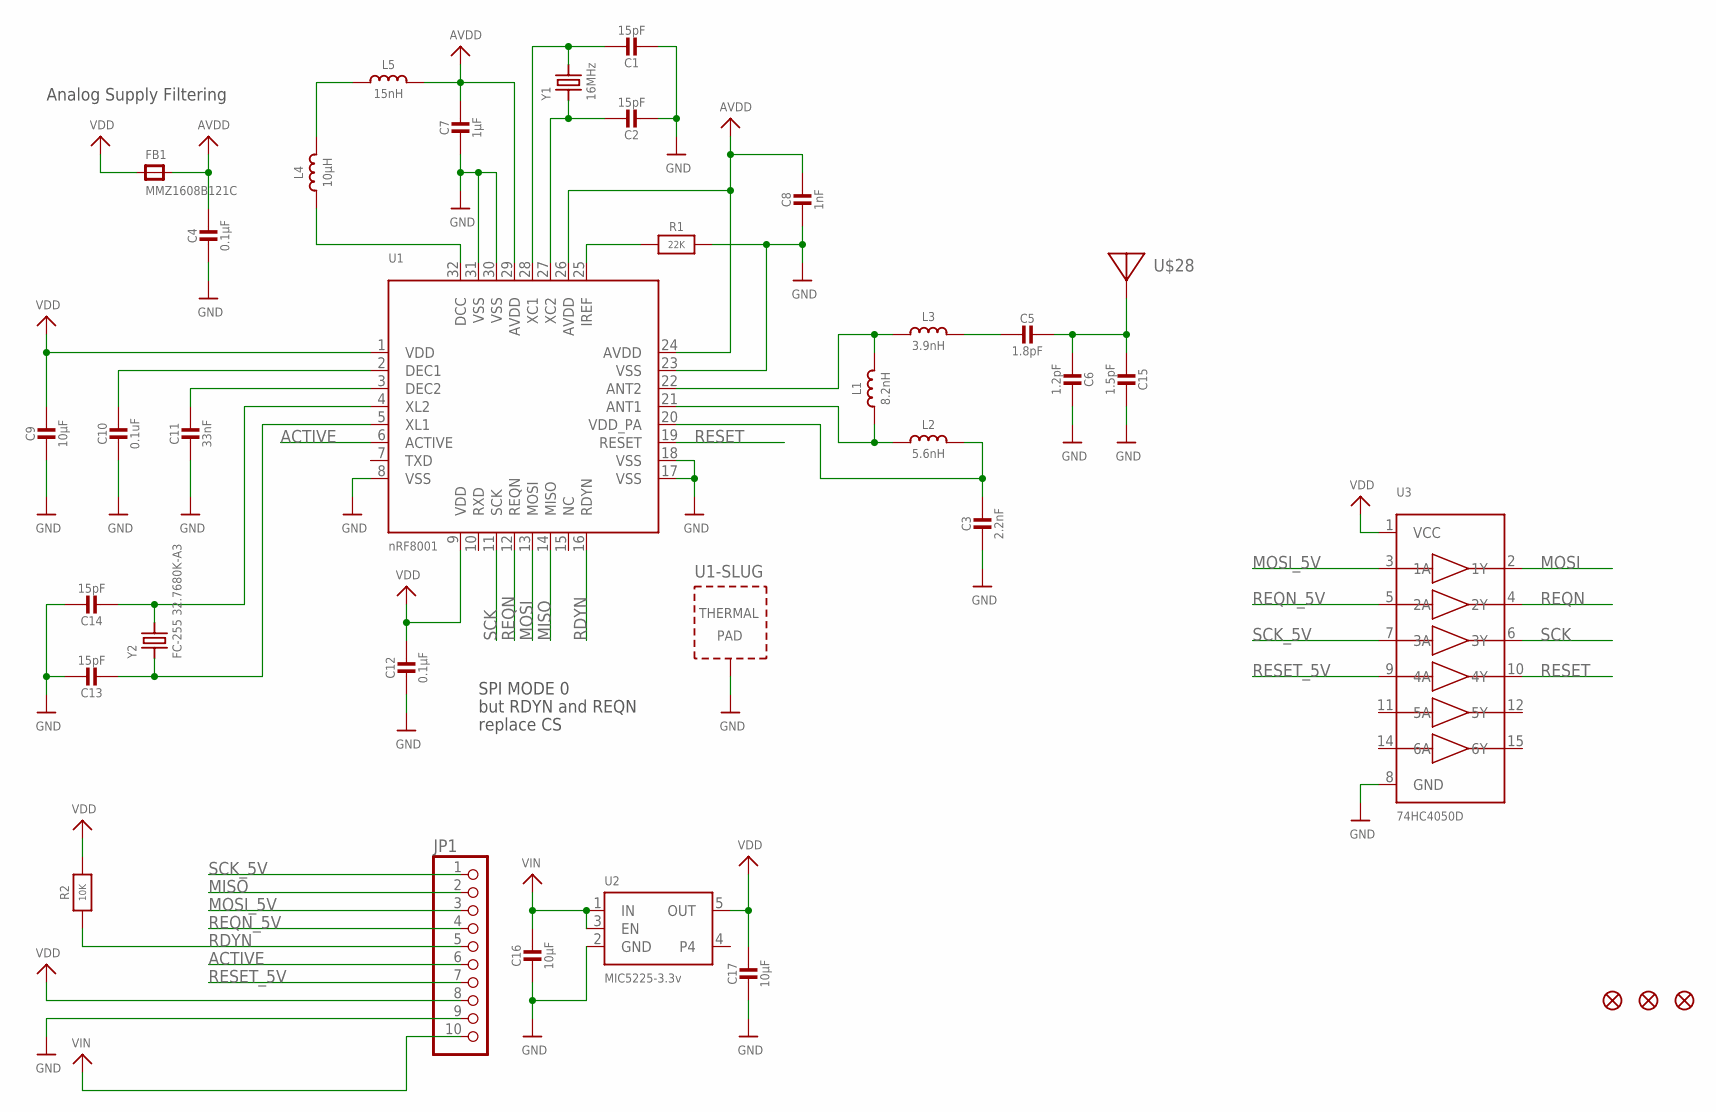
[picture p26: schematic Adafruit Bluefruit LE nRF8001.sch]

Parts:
C1, C2, C13, C14: 15pF; 0805-NO
C3: 2.2nF; _0402
C4, C12: 0.1µF; 0805-NO
C5: 1.8pF; _0402MP
C6: 1.2pF; _0402MP
C7: 1µF; 0805-NO
C8: 1nF; _0603
C9, C16, C17: 10µF; 0805-NO
C10: 0.1uF; 0805-NO
C11: 33nF; 0805-NO
C15: 1.5pF; _0402MP
FB1: MMZ1608B121C; 0805
FID1, FID2, FID3: FIDUCIAL""; FIDUCIAL_1MM
JP1: HEADER-1X1070MIL; 1X10_ROUND70
L1: 8.2nH; _0402
L2: 5.6nH; _0402
L3: 3.9nH; _0402
L4: 10µH; _0603
L5: 15nH; _0603
R1: 22K; _0805MP
R2: 10K; 0805-NO
U1: nRF8001; QFN32_5MM
U2: MIC5225-3.3v; SOT23-5
U3: 74HC4050D; TSSOP16
U$28: ANTENNA_PCBNRF8001_1.6MM; ANT_PCB_2.4GHZ_NRF8001_1.6MM_1OZ
Y1: 16MHz; CRYSTAL_2.5X2
Y2: FC-255 32.7680K-A3; CRYSTAL_4.9X1.8

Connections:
ACTIVE: JP1.6, U1.6 (ACTIVE)
AVDD: C4.1, C7.1, C8.1, FB1.2, L5.2, U1.24 (AVDD), U1.26 (AVDD), U1.29 (AVDD)
GND: C1.2, C2.2, C3.2, C4.2, C6.1, C7.2, C8.2, C9.2, C10.2, C11.2, C12.2, C13.1, C14.1, C15.1, C16.2, C17.2, JP1.9, R1.2, U1.8 (VSS), U1.17 (VSS), U1.18 (VSS), U1.23 (VSS), U1.30 (VSS), U1.31 (VSS), U1.33 (TP), U2.2 (GND), U3.8 (GND)
MISO: JP1.2, U1.14 (MISO)
MOSI: U1.13 (MOSI), U3.2 (1Y)
MOSI_5V: JP1.3, U3.3 (1A)
unnamed: L1.2, L3.1, U1.22 (ANT2)
unnamed: L1.1, L2.1, U1.21 (ANT1)
unnamed: C3.1, L2.2, U1.20 (VDD_PA)
unnamed: L4.2, L5.1
unnamed: C5.2, L3.2
unnamed: C11.1, U1.3 (DEC2)
unnamed: C10.1, U1.2 (DEC1)
unnamed: C1.1, U1.28 (XC1), Y1.3 (2)
unnamed: C2.1, U1.27 (XC2), Y1.1
unnamed: L4.1, U1.32 (DCC)
unnamed: R1.1, U1.25 (IREF)
unnamed: C5.1, C6.2, C15.2, U$28.FEED
unnamed: C14.2, U1.4 (XL2), Y2.2
unnamed: C13.2, U1.5 (XL1), Y2.1
RDYN: JP1.5, R2.1, U1.16 (RDYN)
REQN: U1.12 (REQN), U3.4 (2Y)
REQN_5V: JP1.4, U3.5 (2A)
RESET: U1.19 (RESET), U3.10 (4Y)
RESET_5V: JP1.7, U3.9 (4A)
SCK: U1.11 (SCK), U3.6 (3Y)
SCK_5V: JP1.1, U3.7 (3A)
VDD: C9.1, C12.1, C17.1, FB1.1, JP1.8, R2.2, U1.1 (VDD), U1.9 (VDD), U2.5 (OUT), U3.1 (VCC)
VIN: C16.1, JP1.10, U2.1 (IN), U2.3 (EN)

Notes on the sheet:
Analog Supply Filtering
SPI MODE 0
but RDYN and REQN
replace CS

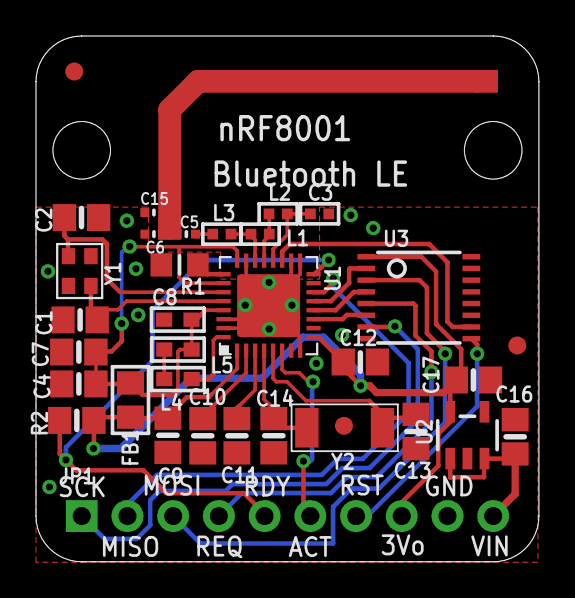
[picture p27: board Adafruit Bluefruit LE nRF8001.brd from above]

Board: 2 copper layers, 27.9 x 29.2 mm, 36 parts (1 on the bottom side), 29 nets.

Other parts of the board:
U$22: ADAFRUIT_TEXT_20MM

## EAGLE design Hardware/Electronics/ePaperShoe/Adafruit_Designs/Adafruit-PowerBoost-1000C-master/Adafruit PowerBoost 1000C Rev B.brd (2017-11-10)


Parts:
B1: JST 2-PH; JSTPH2
C1, C7, C8: 10uF; 0805-NO
C2: 2.2uF; 0805-NO
C4: 0.1uF; 0805_10MGAP
C6: 100uF; C1210
CHRG/LBO: ORANGE; CHIPLED_0805_NOOUTLINE
CN1: USBA_FEMALE; USB_HOST-PTH
CN4: MicroUSB; 4UCONN_20329
DONE: GREEN; CHIPLED_0805_NOOUTLINE
FID1, FID2, FID3: FIDUCIAL""; FIDUCIAL_1MM
JP2: HEADER-1X8ROUND; 1X08_ROUND
L1: 6.8uH; INDUCTOR_5X5MM_TDK_VLC5045
LED1: RED; CHIPLED_0805_NOOUTLINE
LED2: BLUE; CHIPLED_0805_NOOUTLINE
R1: 1.87M; _0805MP
R2: 340K; _0805MP
R3: 1.87M; 0805-NO
R4, R13: 200K; 0805-NO
R5, R8, R14, R20: 1K; 0805-NO
R6: 270K; 0805-NO
R7, R17: 100K; 0805-NO
R9: 43K; 0805-NO
R10: 49.9K; 0805-NO
R11: 75K 1%; 0805-NO
R12: 49.9K 1%; 0805-NO
R16: 1.0K; 0805-NO
T1: MMUN2133LT1G; SC59-BEC
THERM: 15K; 0805-NO
U1: TPS61090RSAR; PVQFN-16
U2: MCP73871; QFN20_4MM
U$10, U$11: MOUNTINGHOLE2.5; MOUNTINGHOLE_2.5_PLATED
X1: TERMBLOCK_1X2; TERMBLOCK_1X2-3.5MM

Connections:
5.0V: C2.1, C6.1, CN1.VBUS, JP2.8, R3.2, R5.1, R9.2, R11.2, U1.1 (VOUT), U1.15 (VOUT), U1.16 (VOUT), X1.2
D+: CN1.D+, R11.1, R12.1
D-: CN1.D-, R9.1, R10.1
ENABLE: JP2.4, R13.2, U1.11 (EN)
GND: B1.1 (-), C1.2, C2.2, C4.2, C6.2, C7.2, C8.2, CN1.GND, CN4.BASE@1 (GND), CN4.BASE@2 (GND), CN4.GND, CN4.SPRT@1 (GND), CN4.SPRT@2 (GND), CN4.SPRT@3 (GND), CN4.SPRT@4 (GND), JP2.5, JP2.7, LED1.C, LED2.C, R2.1, R4.1, R7.2, R10.2, R12.2, R16.1, R17.1, THERM.1, U1.5 (PGND), U1.6 (PGND), U1.7 (PGND), U1.10 (SYNC), U1.13 (GND), U1.P$18 (PGND), U1.P$19 (PGND), U1.P$20 (PGND), U1.P$21 (PGND), U1.P$22 (PGND), U1.THERMAL (PGND), U2.P$10 (VSS1), U2.P$11 (VSS2), U2.P$21 (THERMAL), X1.1
LBO: JP2.6, T1.B, U1.12 (LBO)
unnamed: L1.P$2 (2), U1.3 (SW), U1.4 (SW)
unnamed: LED1.A, R20.1
unnamed: R1.1, R2.2, U1.9 (LBI)
unnamed: LED2.A, R5.2
unnamed: R3.1, R4.2, U1.14 (FB)
unnamed: R20.2, T1.C
unnamed: R6.1, R7.1, U2.P$2 (VPCC)
unnamed: DONE.C, R14.2
unnamed: R14.1, U2.P$7 (STAT2)
unnamed: THERM.2, U2.P$5 (THERM)
unnamed: R8.1, U2.P$8 (STAT1/LBO)
unnamed: CHRG/LBO.C, R8.2
unnamed: R17.2, U2.P$12 (PROG3)
unnamed: R16.2, U2.P$13 (PROG1)
VBAT: C1.1, C4.1, JP2.3, L1.P$1 (1), R1.2, R13.1, T1.E, U1.8 (VBAT), U2.P$1 (VOUT1), U2.P$20 (VOUT2)
VBUS: C8.1, CHRG/LBO.A, CN4.VBUS, DONE.A, JP2.1, R6.2, U2.P$3 (SEL), U2.P$4 (PROG2), U2.P$9 (/TE), U2.P$17 (CE), U2.P$18 (VIN1), U2.P$19 (VIN2)
VLIPO: B1.2 (+), C7.1, JP2.2, U2.P$14 (VBAT1), U2.P$15 (VBAT2), U2.P$16 (VBATSENS)

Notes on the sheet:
Both grounds must be connected on the PCB at only one point close to the GND pin.
On/Off Switch
See Pg 15 1st para
6.8uH power w/2A current
R3 = 1.9Mohm for 5.2V R3 = 1.1Mohm for 3.3V
Charge Rate = 1000V/PROG1
1.0K = 1000mA
2.0K = 500mA
No Thermistor:
10K NTC Thermistor:
RT1 = 0, RT2 = 10K
RT1 = TBD, RT2 = TBD



Board: 2 copper layers, 36.1 x 22.9 mm, 47 parts (2 on the bottom side), 23 nets.

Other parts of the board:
U$12: PCBFEAT-REV-040
U$25: SYMBOL_PLUS
U$26: SYMBOL_MINUS
U$28: ADAFRUIT_5MM
U$45: ADAFRUIT_3.5MM

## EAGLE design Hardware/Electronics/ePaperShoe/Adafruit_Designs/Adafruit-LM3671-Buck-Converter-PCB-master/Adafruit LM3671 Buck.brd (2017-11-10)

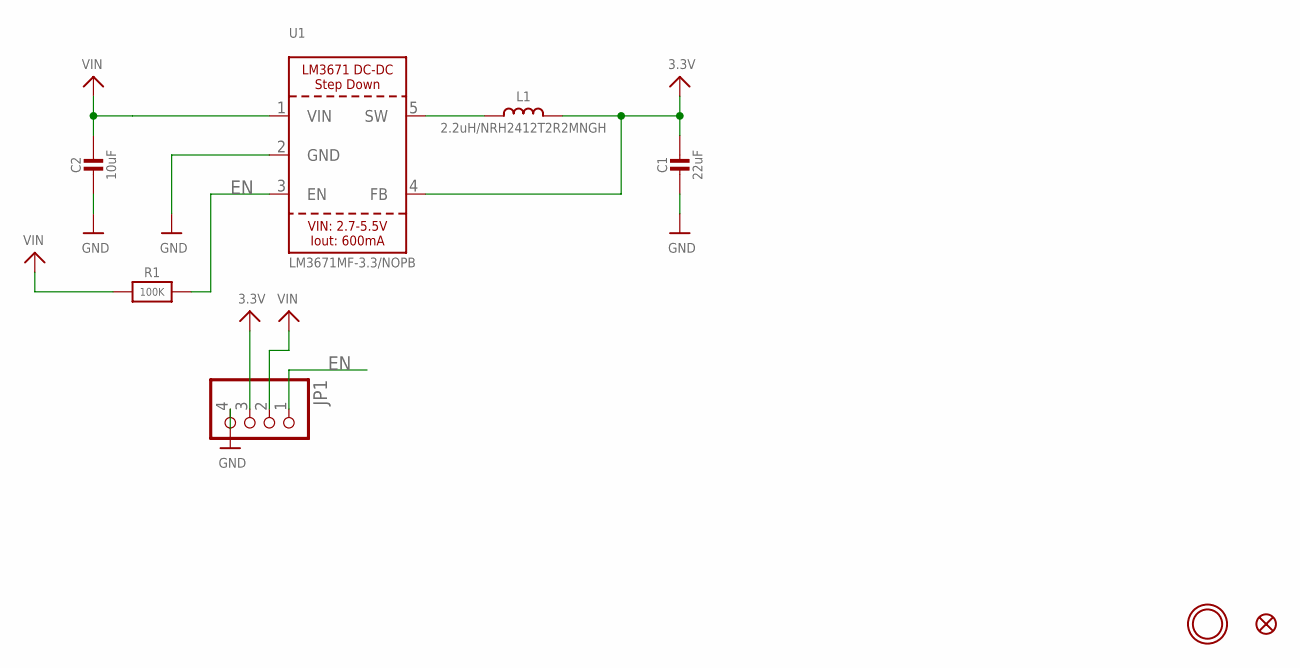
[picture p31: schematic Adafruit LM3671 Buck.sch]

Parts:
C1: 22uF; 0805-NO
C2: 10uF; 0805-NO
FID1: FIDUCIAL""; FIDUCIAL_1MM
JP1: HEADER-1X4ROUND; 1X04_ROUND
L1: 2.2uH/NRH2412T2R2MNGH; INDUCTOR_TAIYOYUDEN_NRH2412T
R1: 100K; 0805-NO
U1: LM3671MF-3.3/NOPB; SOT23-5
U$9: MOUNTINGHOLE2.5; MOUNTINGHOLE_2.5_PLATED

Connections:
3.3V: C1.1, JP1.3, L1.2, U1.4 (FB)
EN: JP1.1, R1.2, U1.3 (EN)
GND: C1.2, C2.2, JP1.4, U1.2 (GND)
unnamed: L1.1, U1.5 (SW)
VIN: C2.1, JP1.2, R1.1, U1.1 (VIN)


Board: 2 copper layers, 10.2 x 15.2 mm, 10 parts (1 on the bottom side), 5 nets.

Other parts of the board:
U$10: PCBFEAT-REV-040
U$11: ADAFRUIT_2.5MM

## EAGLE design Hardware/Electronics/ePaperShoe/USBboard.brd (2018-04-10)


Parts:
CN4: MicroUSB; 4UCONN_20329
FRAME1: FRAME-LETTER-MICHAELNO_PACKAGE; DUMMY
J1: CONN_02; 1X02

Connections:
GND: CN4.BASE@1 (GND), CN4.BASE@2 (GND), CN4.GND, CN4.SPRT@1 (GND), CN4.SPRT@2 (GND), CN4.SPRT@3 (GND), CN4.SPRT@4 (GND), J1.2
unnamed: CN4.VBUS, J1.1


Board: 2 copper layers, 12.7 x 11.4 mm, 3 parts (0 on the bottom side), 2 nets.

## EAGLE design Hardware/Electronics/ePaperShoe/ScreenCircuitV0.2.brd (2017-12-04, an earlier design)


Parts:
C1, C2, C3, C4: 1.0uF; 1206
C5: 0.1uF; 0603
C6, C7: 4.7uF; 1206
D3, D4: 0.5A/40V/420mV; SOD-323
FRAME1: FRAME-LETTER-MICHAELNO_PACKAGE; DUMMY
J1: CONN_08"; 1X08
L1: 47µH/±30%/750mA; CR54
Q1: IRF7509; MSOP8
U1: XF2J-2624-11A; OMRON_XF2J-2624-11A
X1: FH12-26S-0.5SH

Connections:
3.3V: C1.1, J1.8, Q1.5 (D), Q1.6 (D), U1.4, U1.17, U1.18, X1.4, X1.17, X1.18
BUSY_N: J1.3, U1.10, X1.10
GDR_N: Q1.2 (G), U1.21, X1.21
GDR_P: Q1.4 (G), U1.22, X1.22
GND: C1.2, C2.2, C3.2, C4.2, C5.2, C6.2, C7.1, J1.1, Q1.1 (S), U1.2, U1.3, U1.20, X1.2, X1.3, X1.20
unnamed: D3.C, L1.P$1 (1), Q1.3 (S)
unnamed: D4.A, L1.P$2 (2), Q1.7 (D), Q1.8 (D)
RST_N: J1.2, U1.11, X1.11
SPI_CLK: J1.7, U1.13, X1.13
SPI_CS: J1.5, U1.12, X1.12
SPI_MISO: J1.4, U1.15, X1.15
SPI_MOSI: J1.6, U1.14, X1.14
TPCOM: C5.1, U1.1, X1.1
VDD: C4.1, U1.5, U1.19, X1.5, X1.19
VGH: C7.2, D4.C, U1.23, X1.23
VGL: C6.1, D3.A, U1.24, X1.24
VPP: U1.16, X1.16
VSH: C3.1, U1.25, X1.25
VSL: C2.1, U1.26, X1.26

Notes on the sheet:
ZXMD63C03XTA
NSVRB751V40T1G


Board: 2 copper layers, 22.8 x 36.5 mm, 15 parts (0 on the bottom side), 19 nets.

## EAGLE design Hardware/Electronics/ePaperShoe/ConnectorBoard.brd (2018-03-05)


Board: 2 copper layers, 19.3 x 19.2 mm, 3 parts (0 on the bottom side), 26 nets.

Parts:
FRAME1: FRAME-LETTER-MICHAELNO_PACKAGE; DUMMY
X1, X2: FH12-26S-0.5SH

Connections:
unnamed: X1.26, X2.1
unnamed: X1.18, X2.9
unnamed: X1.23, X2.4
unnamed: X1.24, X2.3
unnamed: X1.22, X2.5
unnamed: X1.21, X2.6
unnamed: X1.20, X2.7
unnamed: X1.25, X2.2
unnamed: X1.19, X2.8
unnamed: X1.17, X2.10
unnamed: X1.16, X2.11
unnamed: X1.15, X2.12
unnamed: X1.14, X2.13
unnamed: X1.13, X2.14
unnamed: X1.12, X2.15
unnamed: X1.11, X2.16
unnamed: X1.10, X2.17
unnamed: X1.9, X2.18
unnamed: X1.2, X2.25
unnamed: X1.7, X2.20
unnamed: X1.6, X2.21
unnamed: X1.5, X2.22
unnamed: X1.3, X2.24
unnamed: X1.4, X2.23
unnamed: X1.8, X2.19
unnamed: X1.1, X2.26

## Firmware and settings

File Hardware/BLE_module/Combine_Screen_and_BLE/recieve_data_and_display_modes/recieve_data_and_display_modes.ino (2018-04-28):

#include <Adafruit_GFX.h>
#include "PL_microEPD.h"
#include "imageData.h"
#include <BLEPeripheral.h>
#include "BLESerial.h"

#define VERSION_NUMBER 1.1

#define EPD_RST     A4      // Please align with your individual wiring
#define EPD_BUSY    A5      // 5 3 Please align with your individual wiring
#define EPD_CS      10
PL_microEPD display(EPD_CS, EPD_RST, EPD_BUSY); 
int i=0;  
int led = 0; // 6 0
//int led2 = 7;

// define pins (varies per shield/board)
#define BLE_REQ   10
#define BLE_RDY   2
#define BLE_RST   9

// create ble serial instance, see pinouts above
BLESerial BLESerial(BLE_REQ, BLE_RDY, BLE_RST);


String recievedLine = "";

void setup() {

    // First setup the screen and display the Bioworld logo at boot
    SPI.begin();                            // Bus initialisation, UC8156 supp. max 10Mhz (writing)
    SPI.beginTransaction(SPISettings(500000, MSBFIRST, SPI_MODE0));//and 6.6Mhz (reading)

    pinMode(led, OUTPUT);   
    //pinMode(led2, OUTPUT);
    digitalWrite(led, HIGH); 
    //digitalWrite(led2, HIGH); 

    // Mark the begining of the program by flashing an LED
    digitalWrite(led, LOW);
    delay(100); 
    digitalWrite(led, HIGH);
    delay(100); 
    digitalWrite(led, LOW);

    // Paperino ePaper initialisation and refresh screen 
    display.begin();

    // Display version number
    display.setCursor(1,1);                 // Set Cursor start position 
    display.println(VERSION_NUMBER);

    delay(500);
    // Draw the bitmap:
    // drawBitmap(x position, y position, bitmap data, bitmap width, bitmap height, color)
    display.drawBitmap(0, 0, BioworldLogo, 312, 74, EPD_BLACK);
    // Trigger a full image update
    display.update();

    digitalWrite(led, LOW);
    delay(500); 
    digitalWrite(led, HIGH);
    delay(500); 
    digitalWrite(led, LOW);
    delay(200); 
    
    // Start the bluetooth service
    // custom services and characteristics can be added as well
    BLESerial.setLocalName("ePaper_Shoe");
    BLESerial.begin();

    // Mark the end of the boot by turning off the LED
    digitalWrite(led, HIGH);
    
}

void loop() {
  BLESerial.poll();

  getBluetoothData();
}


// Returns the data recieved from bluetooth as a string
void getBluetoothData() {

    //digitalWrite(led2, LOW);
    
    // Get data from bluetooth
    if (BLESerial) {
        int byte;
        recievedLine = "";
        while ((byte = BLESerial.read()) > 0) {
            // Add each new character to the end of the string
            recievedLine += (char)byte;
            // If newline character, return the string
            if((char)byte == '\n') {
                //digitalWrite(led2, HIGH);
                selectMode();
            }
        }
    }
}

// Recieves string, which is the data recieved from bluetooth and determines the mode function to go to
void selectMode() {
  char recievedData[20] = "";
  strcpy(recievedData, recievedLine.c_str());

  switch(recievedData[0]) {
    case '0':
      displayVersionNumber();
      break;
    case '1':
      displayProgrammedImage(recievedData[1]);
      break;
    case '2':
      displayText(recievedData);
      break;
    case '3':
      loopImages(recievedData[1]);
      break;
    default:
      display.clear();
      display.setCursor(1,1);
      display.println("Invalid Mode Number");
      display.update();
  }
}

// Dispaly the version number of the software on the screen (Mode 0)
void displayVersionNumber() {
  display.clear();
  display.setCursor(1,1);
  display.print("Version: ");
  display.print(VERSION_NUMBER);
  display.update();
}

// Display the image specified after the mode number (Mode 1)
void displayProgrammedImage(char imageNumChar) {
  switch(imageNumChar) {
    case '0':
      display.clear();
      display.drawBitmap(0, 0, gramophoneLGray, 312, 74, EPD_LGRAY);
      display.drawBitmap(0, 0, gramophoneDGray, 312, 74, EPD_DGRAY);
      display.drawBitmap(0, 0, gramophoneBlack, 312, 74, EPD_BLACK);
      display.update();
      break;
    case '1':
      display.clear();
      display.drawBitmap(0, 0, MountainsLGray, 312, 74, EPD_LGRAY);
      display.drawBitmap(0, 0, MountainsDGray, 312, 74, EPD_DGRAY);
      display.drawBitmap(0, 0, MountainsBlack, 312, 74, EPD_BLACK);
      display.update();
      break;
    case '2':
      display.clear();
      display.drawBitmap(0, 0, BarnLGray, 312, 74, EPD_LGRAY);
      display.drawBitmap(0, 0, BarnDGray, 312, 74, EPD_DGRAY);
      display.drawBitmap(0, 0, BarnBlack, 312, 74, EPD_BLACK);
      display.update();
      break;
    case '3':
      display.clear();
      display.drawBitmap(0, 0, A380LGray, 312, 74, EPD_LGRAY);
      display.drawBitmap(0, 0, A380DGray, 312, 74, EPD_DGRAY);
      display.drawBitmap(0, 0, A380Black, 312, 74, EPD_BLACK);
      display.update();
      break;
    case '4':
      display.clear();
      display.drawBitmap(0, 0, BioworldLogo, 312, 74, EPD_BLACK);
      display.update();
      break;
    default:
      display.clear();
      display.setCursor(1,1);
      display.println("Invalid Image Number");
      display.update();
  }
}

// Displays the text after the mode number (Mode 2)
void displayText(char recievedData[]){
  char text[20];
  int i;

  // Make a new char array but remove the first character (mode character)
  for(i = 0; i < 20; i++) {
    text[i] = recievedData[i + 1];
  }
  text[20] = '\0';

  // Display the text
  display.clear();
  display.setCursor(1,1);
  display.println(text);
  display.update();
}

// Loop and display all the images with a delay is second specified after the mode number(Mode 3)
void loopImages(char secDelayChar) {
  int secDelay = int(secDelayChar) - 48;
  int numImages = 4;
  int i;
  while(1){
    for(i = 0; i < numImages; i++) {
      displayProgrammedImage(i + 48);
      delay(secDelay *1000);
    }
  }
}

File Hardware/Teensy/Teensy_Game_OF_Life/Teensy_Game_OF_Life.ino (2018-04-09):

/* ****************************************************************************************
   Test program for displaying images on the Plastic Logic ePaper displays
**************************************************************************************** */
#include <Adafruit_GFX.h>
#include "PL_microEPD.h"

#define XGRID 29
#define YGRID 14
#define NUM_RUNS 80
#define DELAY 400

#define EPD_RST     A4      // Please align with your individual wiring
#define EPD_BUSY    A5      // Please align with your individual wiring
#define EPD_CS      10
PL_microEPD display(EPD_CS, EPD_RST, EPD_BUSY); 

bool mainGrid[XGRID][YGRID];
bool editGrid[XGRID][YGRID];

int runs = 0;

void setup() {
  
  SPI.begin();                            // Bus initialisation, UC8156 supp. max 10Mhz (writing)
  SPI.beginTransaction(SPISettings(4000000, MSBFIRST, SPI_MODE0));//and 6.6Mhz (reading)

  // Paperino ePaper initialisation and refresh screen 
  display.begin();

  clearMainGrid();
  setInitialCells();
  drawGrid();
  display.update();
  delay(1000);
  displayMainGridCells();
  drawGrid();
  display.update(EPD_UPD_MONO);
  delay(DELAY);

}

void loop() {

  // Increment the number of runs
  runs++;

  // Restart the game after so many runs
  if(runs == NUM_RUNS){
    clearMainGrid();
    setInitialCells();
    runs = 0;
    display.update();
  }

  // Normal run opperation
  display.clear();
  applyRules();
  copyEditGridToMainGrid();
  displayMainGridCells();
  drawGrid();
  display.update(EPD_UPD_MONO);
  delay(DELAY);
  

}

// Clears the main grid
void clearMainGrid() {
  int i, j;
  for(i = 0; i < XGRID; i++) {
    for(j = 0; j < YGRID; j++) {
      mainGrid[i][j] = false;
    }
  }
}


// Sets the initial grid bits
void setInitialCells() {
  
//  // Blinker
  mainGrid[6][10] = true;
  mainGrid[6][11] = true;
  mainGrid[6][12] = true;

  // Glider
  mainGrid[8][7] = true;
  mainGrid[9][8] = true;
  mainGrid[10][6] = true;
  mainGrid[10][7] = true;
  mainGrid[10][8] = true;

  // Glider2
  mainGrid[14][11] = true;
  mainGrid[15][12] = true;
  mainGrid[16][10] = true;
  mainGrid[16][11] = true;
  mainGrid[16][12] = true;
 
  // Beacon
  mainGrid[0][0] = true;
  mainGrid[0][1] = true;
  mainGrid[1][0] = true;
  mainGrid[1][1] = true;
  mainGrid[2][2] = true;
  mainGrid[2][3] = true;
  mainGrid[3][2] = true;
  mainGrid[3][3] = true;

  // Pentadecathlon
  mainGrid[14][3] = true;
  mainGrid[14][4] = true;
  mainGrid[14][5] = true;
  mainGrid[15][2] = true;
  mainGrid[15][6] = true;
  mainGrid[16][1] = true;
  mainGrid[16][7] = true;
  mainGrid[18][0] = true;
  mainGrid[18][8] = true;
  mainGrid[19][0] = true;
  mainGrid[19][8] = true;
  mainGrid[23][3] = true;
  mainGrid[23][4] = true;
  mainGrid[23][5] = true;
  mainGrid[22][2] = true;
  mainGrid[22][6] = true;
  mainGrid[21][1] = true;
  mainGrid[21][7] = true;

  // Square
  mainGrid[27][12] = true;
  mainGrid[27][12] = true;
  mainGrid[28][13] = true;
  mainGrid[28][13] = true;

  // Glider Gun
//  mainGrid[1][6] = true;
//  mainGrid[1][7] = true;
//  mainGrid[2][6] = true;
//  mainGrid[2][7] = true;
//
//  mainGrid[11][6] = true;
//  mainGrid[11][7] = true;
//  mainGrid[11][8] = true;
//  mainGrid[12][5] = true;
//  mainGrid[12][9] = true;
//  mainGrid[13][4] = true;
//  mainGrid[13][10] = true;
//  mainGrid[14][4] = true;
//  mainGrid[14][10] = true;
//  mainGrid[15][7] = true;
//  mainGrid[16][5] = true;
//  mainGrid[16][9] = true;
//  mainGrid[17][6] = true;
//  mainGrid[17][7] = true;
//  mainGrid[17][8] = true;
//  mainGrid[18][7] = true;
//
//  mainGrid[21][4] = true;
//  mainGrid[21][5] = true;
//  mainGrid[21][6] = true;
//  mainGrid[22][4] = true;
//  mainGrid[22][5] = true;
//  mainGrid[22][6] = true;
//  mainGrid[23][3] = true;
//  mainGrid[23][7] = true;
//  mainGrid[25][2] = true;
//  mainGrid[25][3] = true;
//  mainGrid[25][7] = true;
//  mainGrid[25][8] = true;
//
//  mainGrid[35][4] = true;
//  mainGrid[35][5] = true;
//  mainGrid[35][4] = true;
//  mainGrid[35][5] = true;

  // Toad
  mainGrid[2][7] = true;
  mainGrid[3][7] = true;
  mainGrid[4][7] = true;
  mainGrid[1][8] = true;
  mainGrid[2][8] = true;
  mainGrid[3][8] = true;
  
}


// Draws the grid
void drawGrid() {
  int i, j;
  for(i = 0; i <= XGRID; i++) {
    display.drawLine(i*5, 0, i*5, YGRID*5, EPD_LGRAY);
  }
  for(j = 0; j < YGRID; j++) {
    display.drawLine(0, j*5, XGRID*5, j*5, EPD_LGRAY);
  }
}


// Displays the cells in the main grid
void displayMainGridCells() {
  int i, j;
  for(i = 0; i < XGRID; i++) {
    for(j = 0; j < YGRID; j++) {
      if(mainGrid[i][j] == true) {
         display.fillRect(i*5, j*5, 5, 5, EPD_BLACK);
      }
    }
  }
}


// Apply the rules for game of life to the mainGrid
void applyRules() {
  int i, j, k, l;
  for(i = 0; i < XGRID; i++) {
    for(j = 0; j < YGRID; j++) {
      int neighbors = 0;

      // Check each possible neighbor and see if they are alive
      // If so, add 1 to neighbors for each cell alive 
      for(k = -1; k < 2; k++) {
        for(l = -1; l < 2; l++) {
          // check if valid index
          int x = i+k;
          int y = j+l;
          if(x >= 0 && y >= 0) {
            // Add to neighbors if there is a neighbor at (x,y)
            if(mainGrid[x][y] == true) neighbors++;
          }
        }
      }
      if(mainGrid[i][j] == true) neighbors--;

      // Apply the rules to the cell based on the value of neighbors
      if(mainGrid[i][j]) {  // if alive
        if(neighbors < 2 || neighbors > 3) {
          editGrid[i][j] = false; // check for overpopulation or underpopulation
        }
        else {
          editGrid[i][j] = true;
        }
      }
      else {  // if dead
        if(neighbors == 3) {
          editGrid[i][j] = true;
        }
        else {
          editGrid[i][j] = false;
        }
      }
    }
  }
}

void copyEditGridToMainGrid() {
  memcpy(mainGrid, editGrid, XGRID*YGRID*sizeof(bool));
}

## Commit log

2017-11-10 Started schematic and added power circuits
    [ePaperShoe.sch]
2017-11-10 Made Red Bear LED alternate between on and off when recieving a byte over BLE UART
2017-11-10 Added designes from Adafruit for some parts purchased from them
    [Adafruit LM3671 Buck.brd, Adafruit LM3671 Buck.sch, Adafruit PowerBoost 1000C Rev B.brd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]
2017-11-17 added circuit for driving screen
    [ScreenCircuitV0.1.brd, ScreenCircuitV0.1.sch, ePaperShoe.sch]
2017-11-23 Changes made to the screen circuit
    [ScreenCircuitV0.1.brd, ePaperShoe.sch]
2017-12-04 Made screen circuit version 0.2
    [MicrocontrollerCircuit.sch, PowerCircuit.brd, PowerCircuit.csv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]
2018-01-10 Attempt on screen driver and PCB design for Nordic chip
    [Adafruit Bluefruit LE nRF8001 v2.brd, Adafruit Bluefruit LE nRF8001 v2.sch, Adafruit Bluefruit LE nRF8001.brd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]
2018-01-17 Finished design on the nRF52 schematic
    [MicrocontrollerCircuit.sch]
2018-01-23 Minor adjustments to the to nRF52 PCB
    [400148.DRL, 400148.GBL, 400148.GBO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]
2018-01-25 Finished design of microcontroller circuit and added logic analyser snapshots
    [MicrocontrollerCircuit.brd]
2018-01-26 moved file to new location
    [400148.DRL, 400148.GBL, 400148.GBO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]
2018-01-30 Added Paperino Arduino example code
2018-03-03 Created Connector board to conect the screen to a ribbon cable
    [ConnectorBoard.brd, ConnectorBoard.sch]
2018-03-05 Designed new screen board and made minor changes to the connector board
    [ConnectorBoard.brd, ScreenCircuitV1.brd, ScreenCircuitV1.sch]
2018-04-09 Version 1.0 for Teensy game of life
2018-04-10 Designed microcontroller board V2 and USB board
    [MicrocontrollerCircuitV2.brd, MicrocontrollerCircuitV2.sch, USBboard.brd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]
2018-04-11 Completed final schematic diagram, started PCD design
    [Adafruit Bluefruit LE nRF8001 v2.brd, Adafruit Bluefruit LE nRF8001 v2.sch, Adafruit Bluefruit LE nRF8001.brd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]
2018-04-11 Completed layout and traces of PCB. Need to still add silkscreen and arrange lables
    [Complete_ePaper_Shoe_Board.brd, Complete_ePaper_Shoe_Board.sch]
2018-04-12 Completed PCB with everything on it V1.0
    [Complete_ePaper_Shoe_Board.brd]
2018-04-28 Changes here and there, refining the product
    [Complete_ePaper_Shoe_Board.brd, Complete_ePaper_Shoe_Board.sch]

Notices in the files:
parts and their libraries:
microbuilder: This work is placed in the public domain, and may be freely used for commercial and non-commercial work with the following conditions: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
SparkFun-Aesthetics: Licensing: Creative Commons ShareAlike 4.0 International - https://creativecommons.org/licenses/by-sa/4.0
